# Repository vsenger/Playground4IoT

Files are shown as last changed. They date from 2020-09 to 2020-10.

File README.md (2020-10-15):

# Playground4IoT

*"There are three states of being: Not knowing, action and completion"*
Cult of Done Manifesto, Bre Pettis

Welcome Playgrounder to our repository where you can find libraries, firmwares, Arduino Sketch, tutorials and more for Playground4IoT development board. Playground4IoT is a development board that make easy and fun to start playing, prototyping and deploying connected devices projects using AWS Services like AWS IoT Core and Amazon FreeRTOS with security for adults, deployment over-the-air and management of big fleets of devices in production.

This project was done by AWS Developer Relations Team but is open-source, don't hesitate to clone it, produce, have fun, make money, change the world or anything else you dream. Developer Relations Team exist to help you to make it happen, count on us.. ALWAYS!

## Technical Resume

*"Accept that everything is a draft. It helps to get it done."*
The Cult of Done Manifesto, Bre Pettis

This board is based on ESP32, a powerful SoC that can run in low-energy with solar panel and simple battery forever and you can program using Arduino IDE, libraries and frameworks or you can go deeper and programa with Amazon FreeRTOS for industry ready devices.

* Based on ESP32 SoC (System-on-chip) with WIFI and Bluetooth
* Accelerometer Sensor
* Temperature, Humidity and Pressure sensor
* Light sensor
* Battery voltage sensor
* Solar panel sensor
* Groovy connectors
* External Solar Panel Connector
* External Battery Connector
* Battery charger system (cable / solar panel)
* And a lot of love!

## Let's Play!

*"People without dirty hands are wrong, doing something makes you right!"*
The Cult of Done Manifesto, Bre Pettis

Here we have a simple description image showing the main parts:

1. Power on / off
2. IoT Button: you can use as IoT button or anything else!
3. The loooovely OLED display: you can code turn on and off to save energy, sure thing!
4. ESP32: the core! and it's compatible with Amazon FreeRTOS and very cheap
5. GPIO: the place you can extend in a "maker way"
6. Reset Button
7. Solar panel connector: yesss! I can survive with Sun, at least in Brazil ahahah
8. External Battery Connector
9. USB C: you can use to charge the battery (nice!!!), to upload firmware hard-wire (but you can do it over-the-air!) or to debug your board
10. USB to Serial Controller: this is the CH340 chip, you may need or not to install a driver for it
11. You will find three additional connectors under the board and they are Grove compatible, so you can plug [200+ different sensors](https://www.seeedstudio.com/catalogsearch/result/index/?cat=890&q=grove).

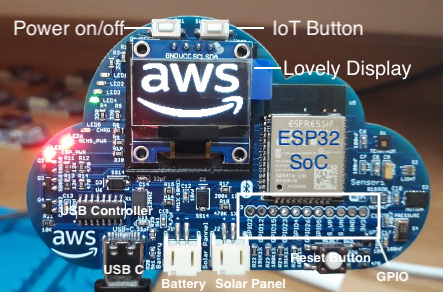
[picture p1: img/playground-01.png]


To start playing with this device (or toy?!?) we have those main steps:
1. Install Playground4IoT usb driver
1. Install and setup Arduino IDE environment: install Arduino IDE itself and setup for E	SP32 development 
1. Install Arduino libraries for the Playground4IoT sensors
1. Create a thing to represent your board in AWS IoT Core
1. Setup the wifi credential, root-ca, device certificate and private key inside the Arduino C code
1. Upload the Arduino code to your board using an USB cable
1. Open AWS IoT Core console and start playing with your board

Now let's go deep in each step!

## 1. Install Playground4IoT usb driver

Our board uses a chip called CH340 to communicate throught the USB-C port, this chip is actualy a Serial - USB converter so once you have the driver installed you will see the Playground4IoT as a Serial port (windows: COM1, COM7, COMx - linux /dev/acm0 /dev/usb0 - macs /dev/cu.wchusbserial). 

> **_NOTE:_**  MacOS Mojave (and newer) already includes a CH34x driver from Apple. Do not install other versions as it may cause issues. Read more on https://github.com/adrianmihalko/ch340g-ch34g-ch34x-mac-os-x-driver/pull/19.

Follow this nice sparkfun.com tutorial to install the driver: https://learn.sparkfun.com/tutorials/how-to-install-ch340-drivers/all

## 2. Arduino IDE

We have different ways to start programming our Playground4IoT that is based on ESP32 SoC and the simple way to do it is using Arduino IDE. It's a very popular IDE / tool for writing firmwares they call sketches using a simplified C sintax with many libraries to abstract all the hardware and C complex code.

To install Arduino IDE go to Arduino Web Site, download and install it, it's quite simlpe. Here is the link: https://www.arduino.cc/en/Main/Software

After installing the Arduino IDE we must add the ESP32 support. 

1) Open your Arduino IDE

2) Go to File -> Preferences

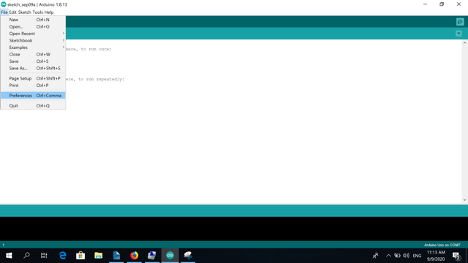
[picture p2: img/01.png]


3) Enter https://dl.espressif.com/dl/package_esp32_index.json into the “Additional Board Manager URLs” field as shown in the figure below. Then, click the “OK” button:

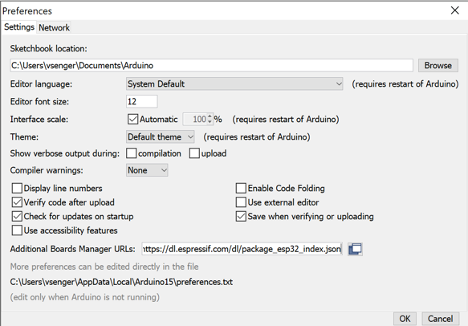
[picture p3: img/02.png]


4) Open the Boards Manager. Go to Tools > Board > Boards Manager…

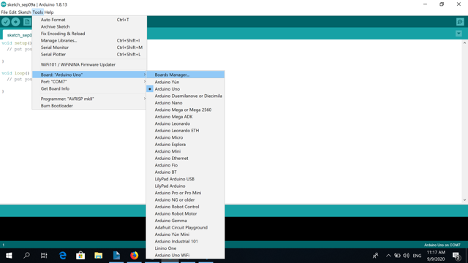
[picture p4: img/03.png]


5) Search for ESP32 and press install button for the “ESP32 by Espressif Systems“:

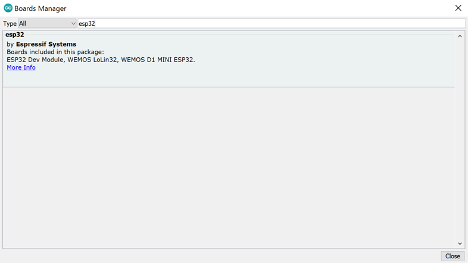
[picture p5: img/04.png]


Now wait until it finish the downlaod and install

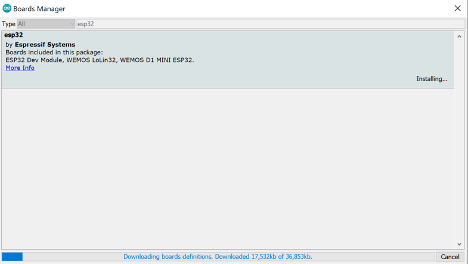
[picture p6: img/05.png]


All done with ESP32 support for Arduino IDE:

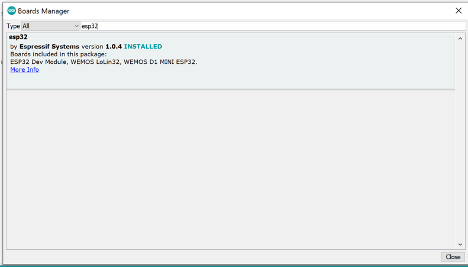
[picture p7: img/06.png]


6) Choose the "ESP32 Dev Module" in boards manager:

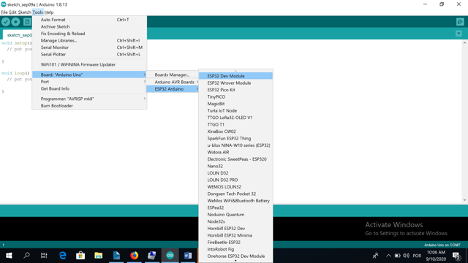
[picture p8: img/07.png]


7) Now it's time to find your USB port, don't plug your board in your computer and check which ports you have on the Tools -> Port menu:

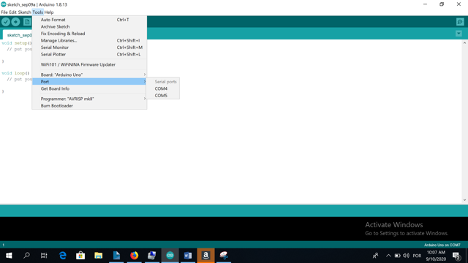
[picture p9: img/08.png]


8) Now plug your Playground4IoT and check this menu again, you should see something new like here that COM7 is the choosen port:

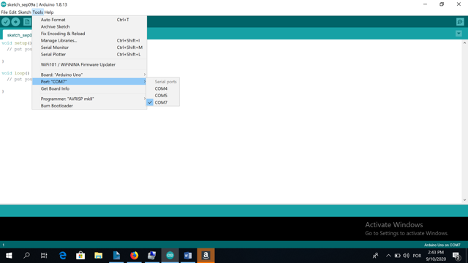
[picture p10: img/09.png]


## 3. Install Arduino Libraries for our Sensors

The Playground for IoT uses some sensors that has specific C libraries to make it easy to use. All we need to do is copy the folders in /Playground4IoT/Arduino/Libraries to your $HOME/Documents/Arduino/Library.

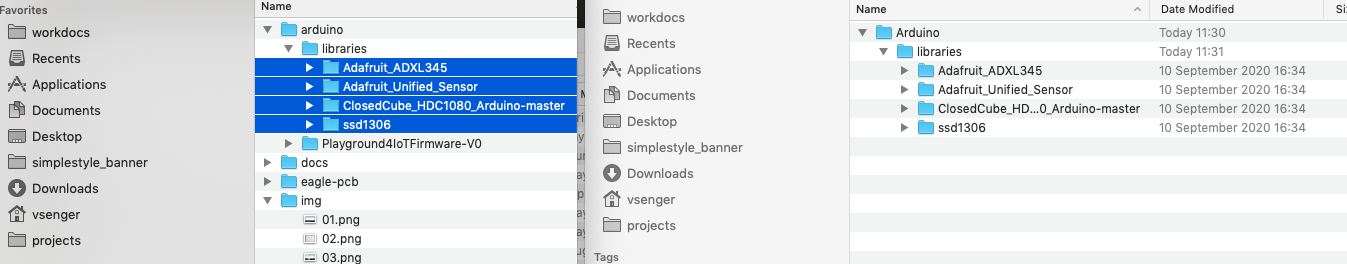
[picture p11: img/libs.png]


## 4. AWS IoT Core Setup

1) Now we need to setup the cloud side of the moon... We will create a thing to represent our Playground4IoT board and also the certificate and security keys. Open your AWS IoT Core Console and click Manage -> Things -> Register a single AWS IoT thing:

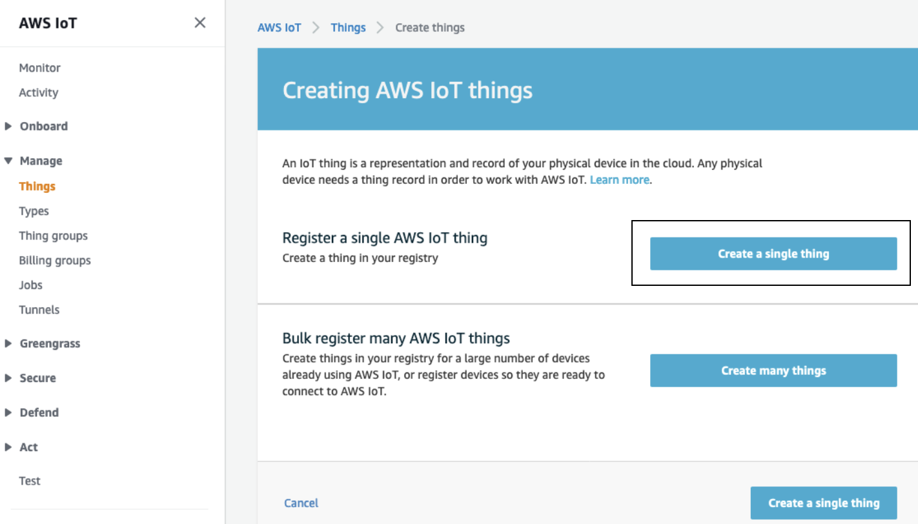
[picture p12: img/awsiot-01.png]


2) Let's choose "Create a single thing"

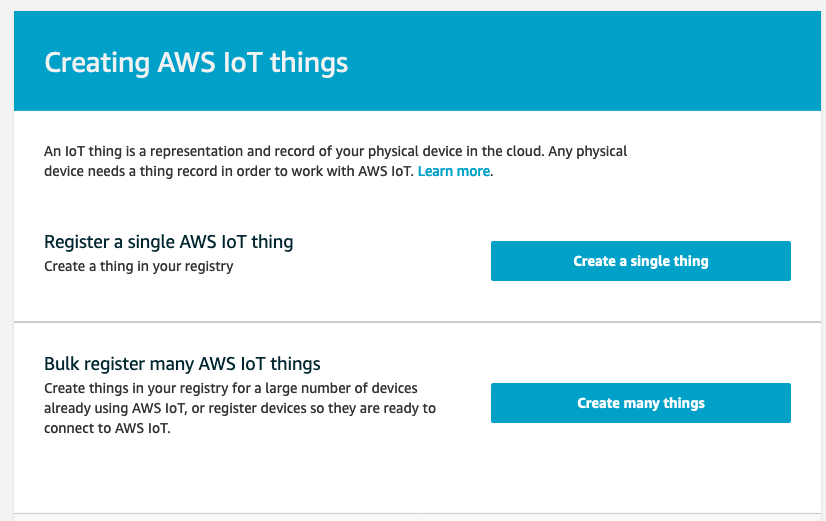
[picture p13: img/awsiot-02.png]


3) Now give a name to your thing and click next

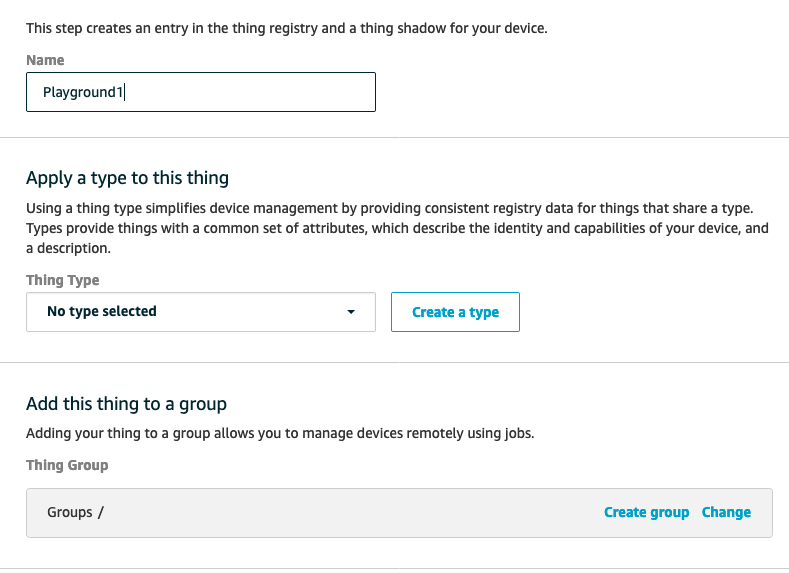
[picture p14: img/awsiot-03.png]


4) Now choose "One-click certificate creation"

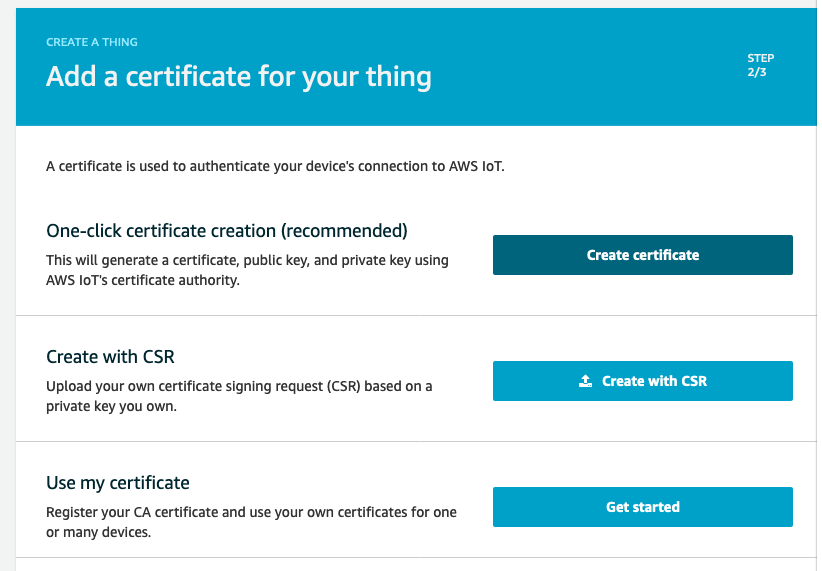
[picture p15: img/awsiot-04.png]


5) You can finally download your thing's certificate and private key

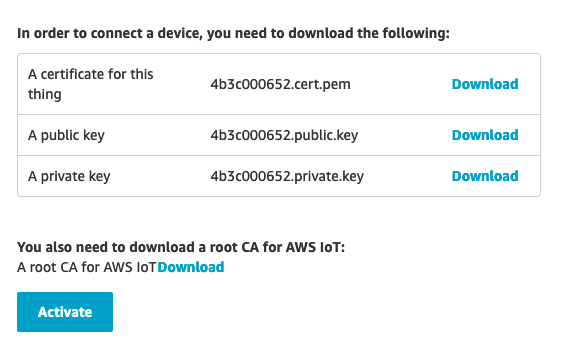
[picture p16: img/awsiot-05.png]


6) Click Activate to make your certicates valid

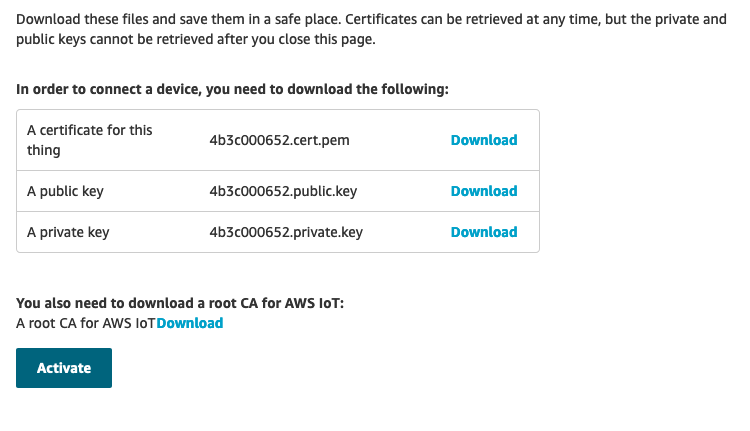
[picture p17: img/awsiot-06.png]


7) Download ROOT Certificate Authority clicking in "A root CA for AWS IoT Download" (this opens the AWS documentation and you'll need to choose one of the CAs on the page)

tutorial image

8) You will be redirected to another page that you can choose some options:

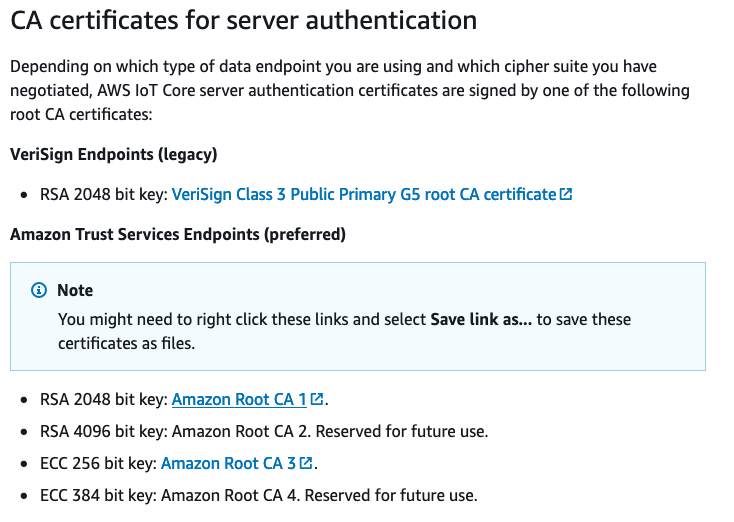
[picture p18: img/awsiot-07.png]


9) Now we need to take note of our AWS IoT Core endpoint to use in the next step. Open AWS IoT Core Console and click settings

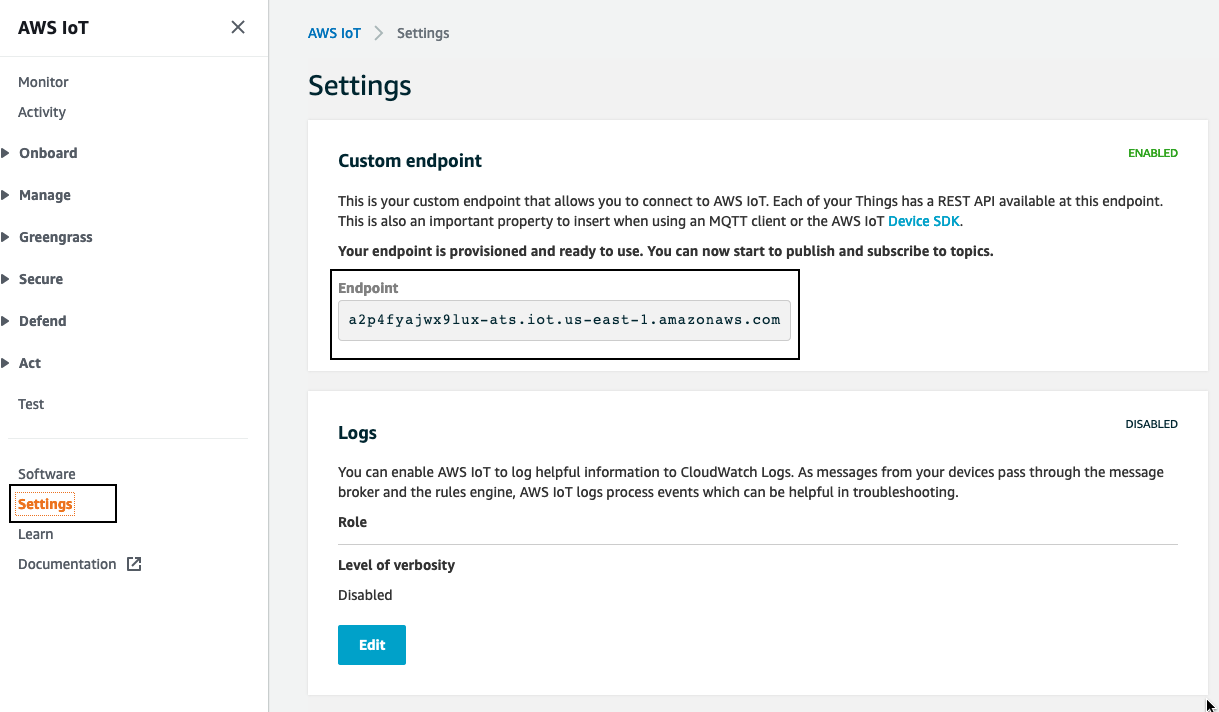
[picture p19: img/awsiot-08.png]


10) We need to create a policy for our device, click Policies -> Create

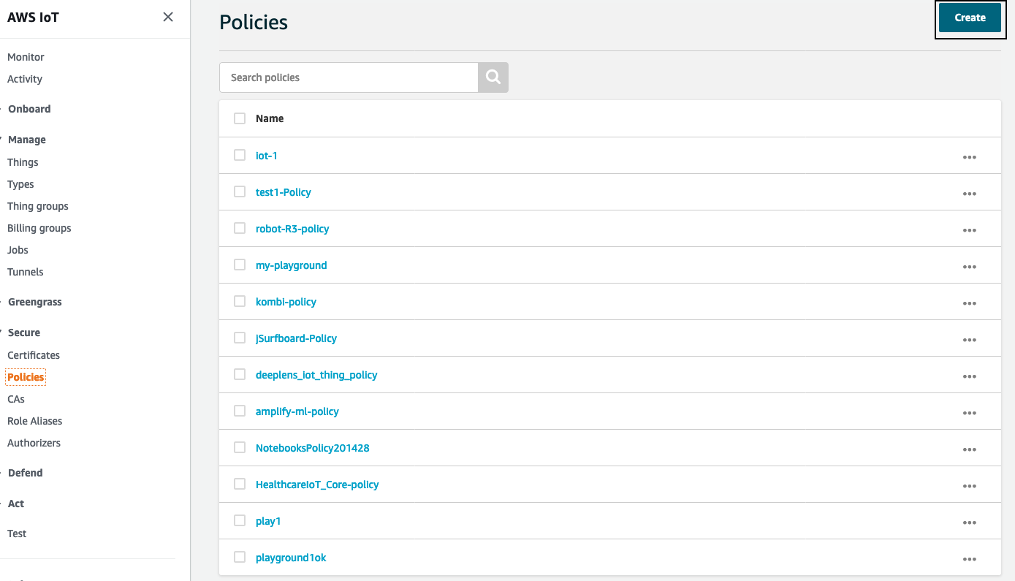
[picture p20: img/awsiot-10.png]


11) Give a name and choose action iot:* and replace topic name with * (just for testing proposal, the policy for real projects should be restrictive!). Choose Effect Allow and click Create

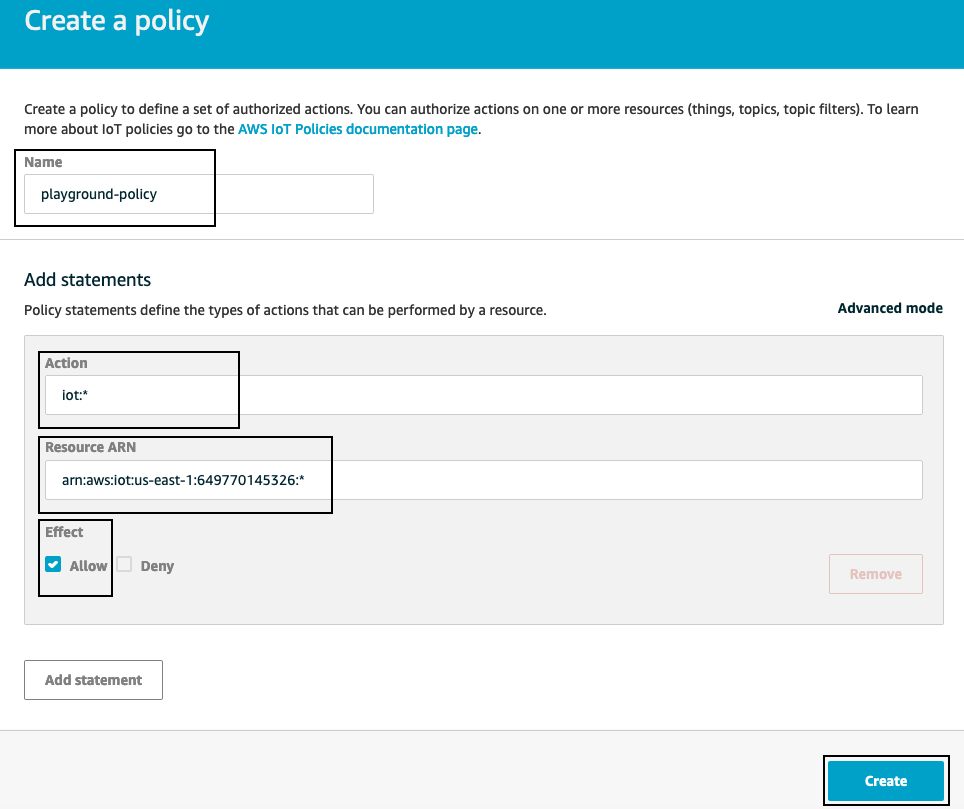
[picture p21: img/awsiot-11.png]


12) Now let's associate the policy with the Thing Certificate, to do this click in the IoT Thing you've created, click Security and then click in the Certificate:

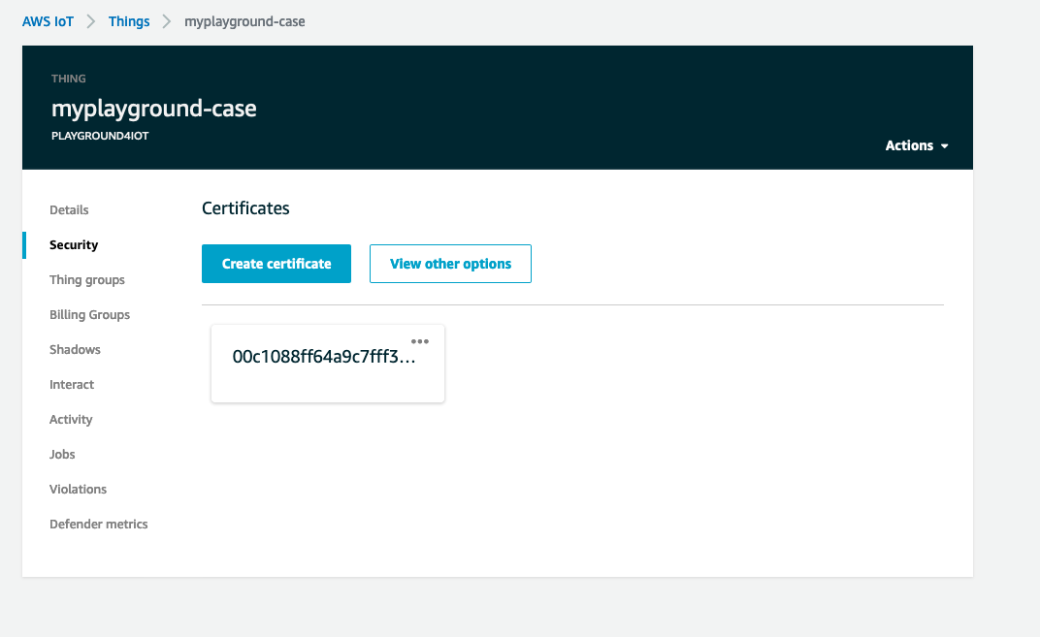
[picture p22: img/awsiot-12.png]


13) Click Policies

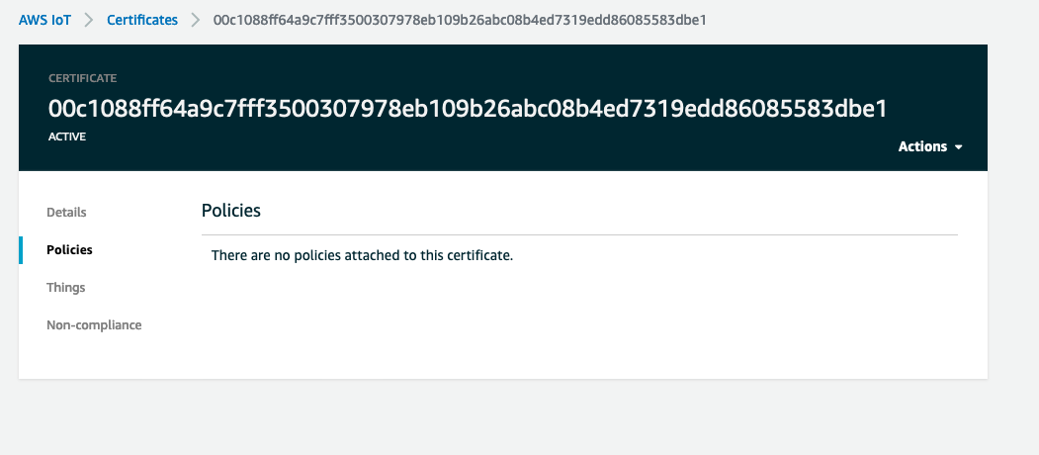
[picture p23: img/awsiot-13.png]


14) Click Actions menu -> Attach Policy

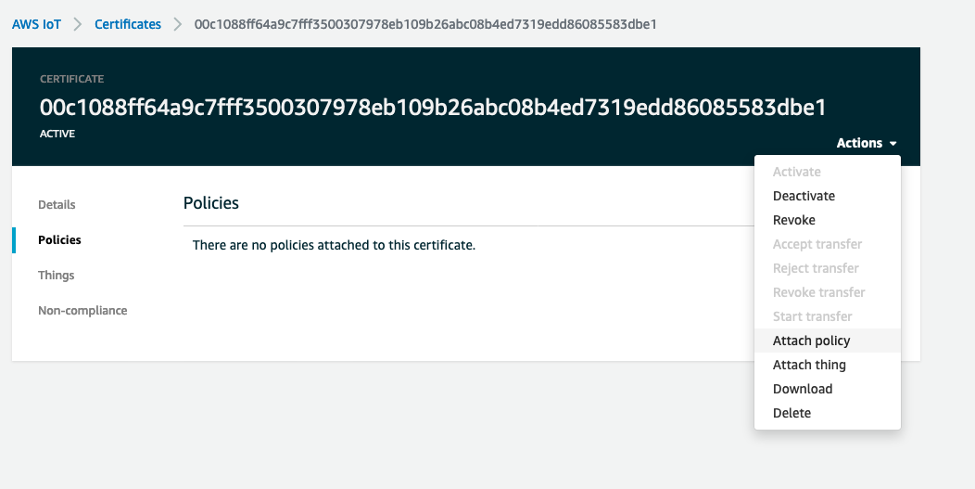
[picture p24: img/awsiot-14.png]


15) Choose the created Policy and click Attach:

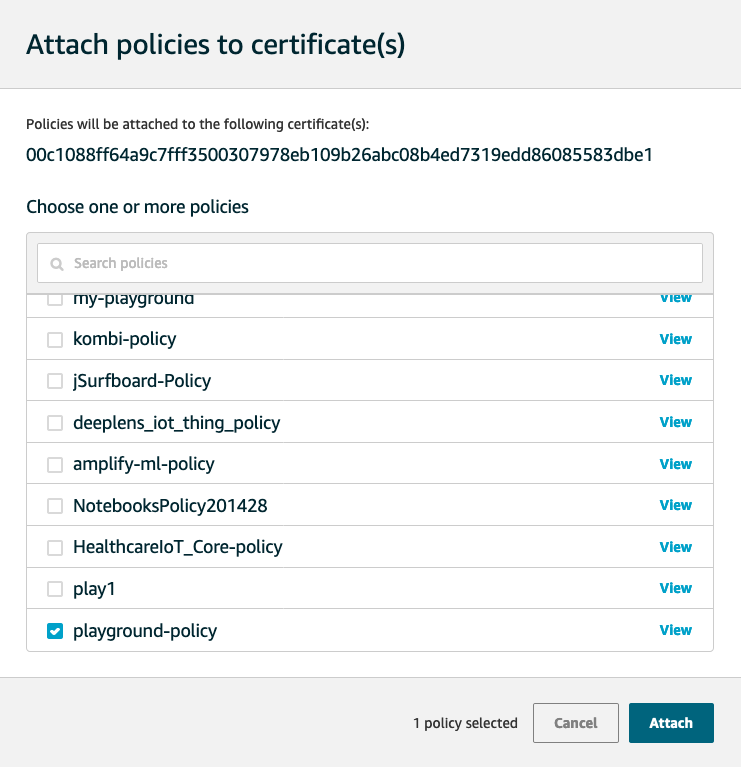
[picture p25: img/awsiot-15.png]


Ufff, done!

## 5. Let's code!

1) Clone Playground4IoT repo: git clone https://github.com/vsenger/Playground4IoT

2) Open your Arduino IDE and make sure you selected the right USB port and ESP32 board!

3) Open the Arduino Sketch with current the firmware located inside the folder you clone the github repo: Playground4IoT/arduino/Playground4IoTFirmware-V0/

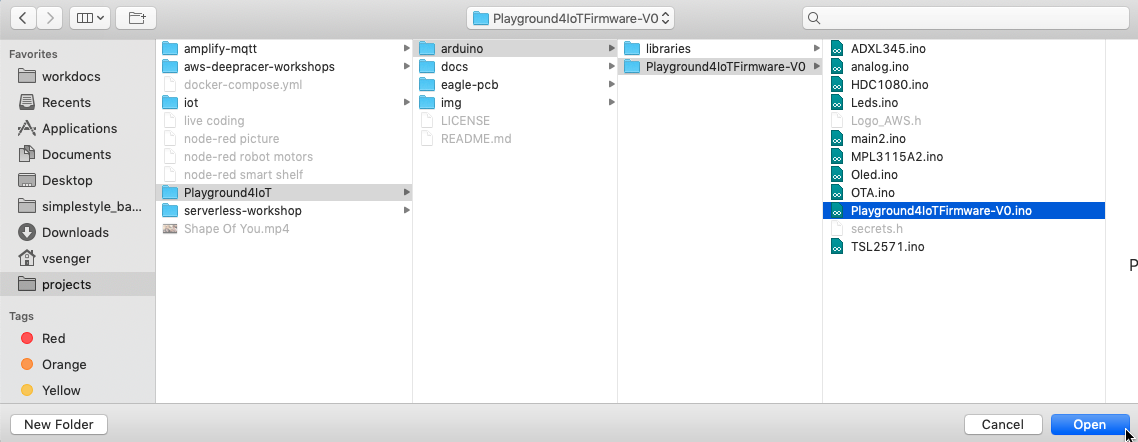
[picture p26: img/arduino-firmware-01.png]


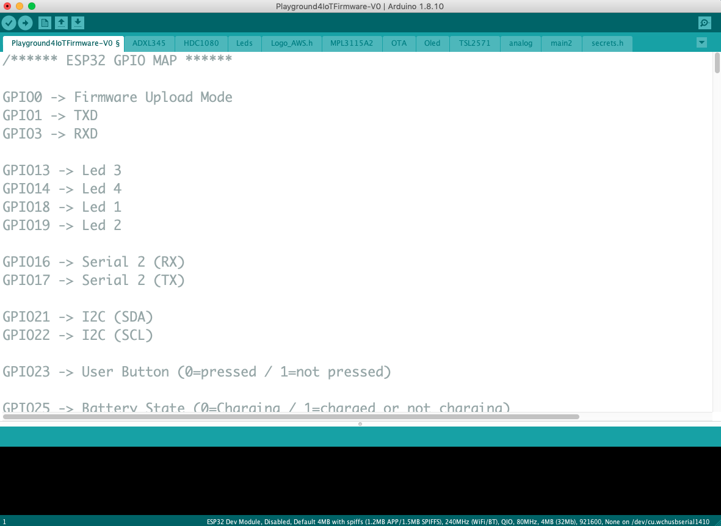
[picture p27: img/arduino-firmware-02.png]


4) Setup your SSID and password: scroll down to the line around 60 and change:

1. The host name to your AWS IoT Core Thing name
2. SSID and passsword
3. Optional: change the name of the topics we are going to use to communicate with our board 

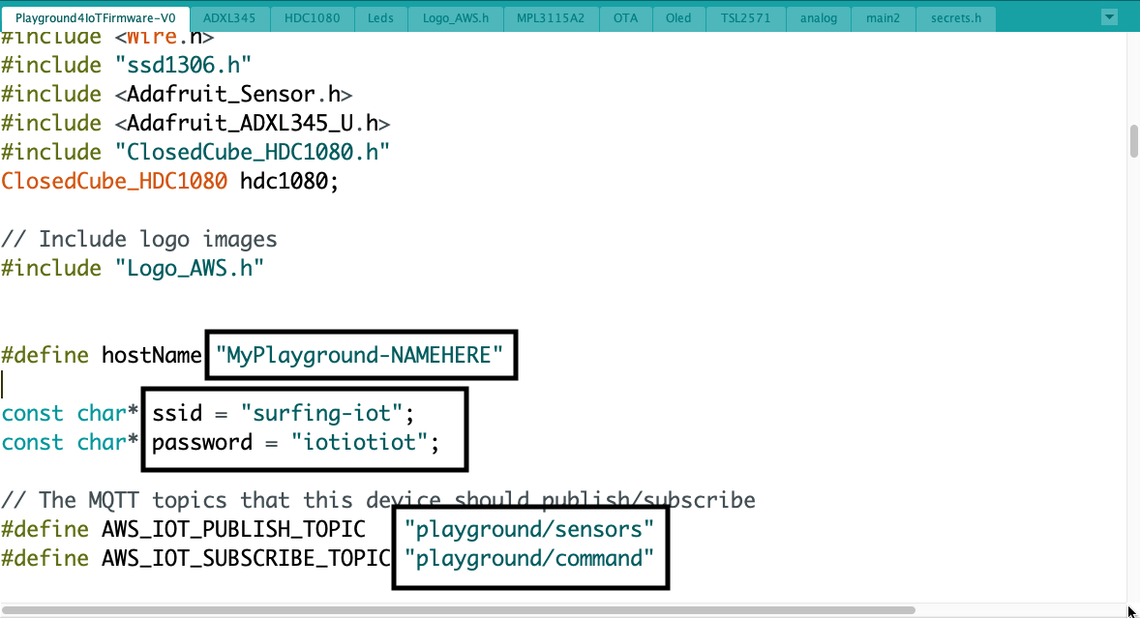
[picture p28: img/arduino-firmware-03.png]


5) Let's configure our credentials: click in secrets.h tab and then update:

1. AWS IoT Core endpoint
2. ROOT CA certificate: open the downloaded file and copy and paste the content
3. Same things for Device Certificate and Private Key. 

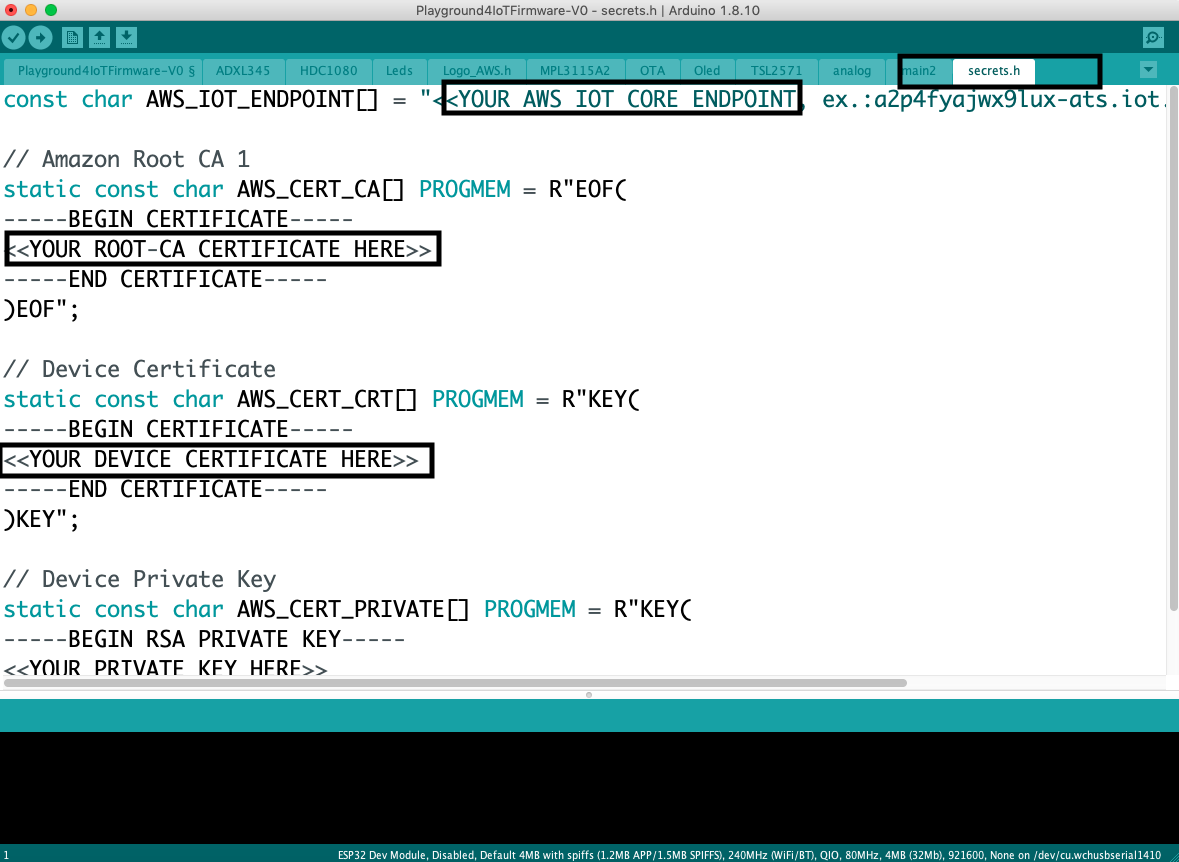
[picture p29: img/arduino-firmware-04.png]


## 6. Upload and fingers crossed

Now click the Upload button and wait until it compile and upload to your board. Keep your eyes in the log message panel, it's "normal" to have warning messages :).

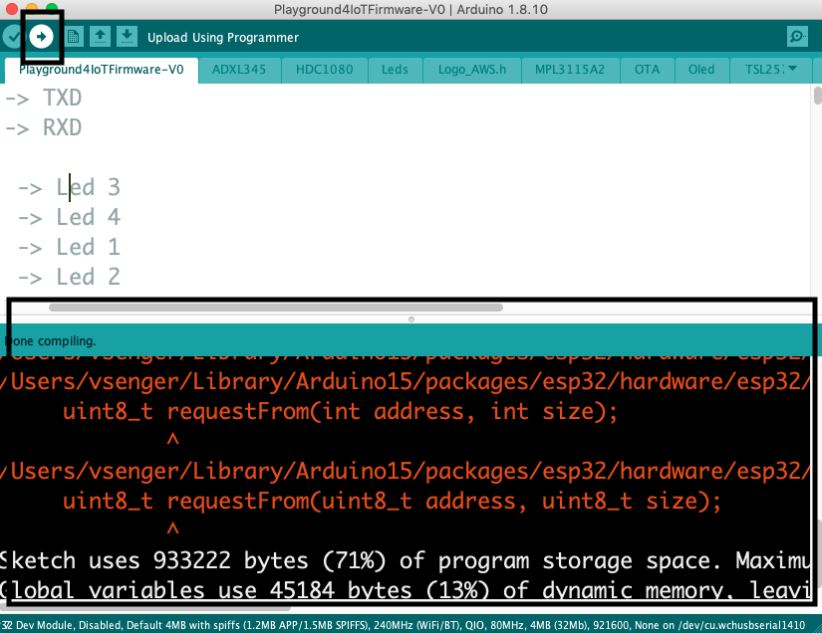
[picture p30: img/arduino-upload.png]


## 7. Let's Play! 

Time to have fun! Open your AWS IoT Core Console and click Test

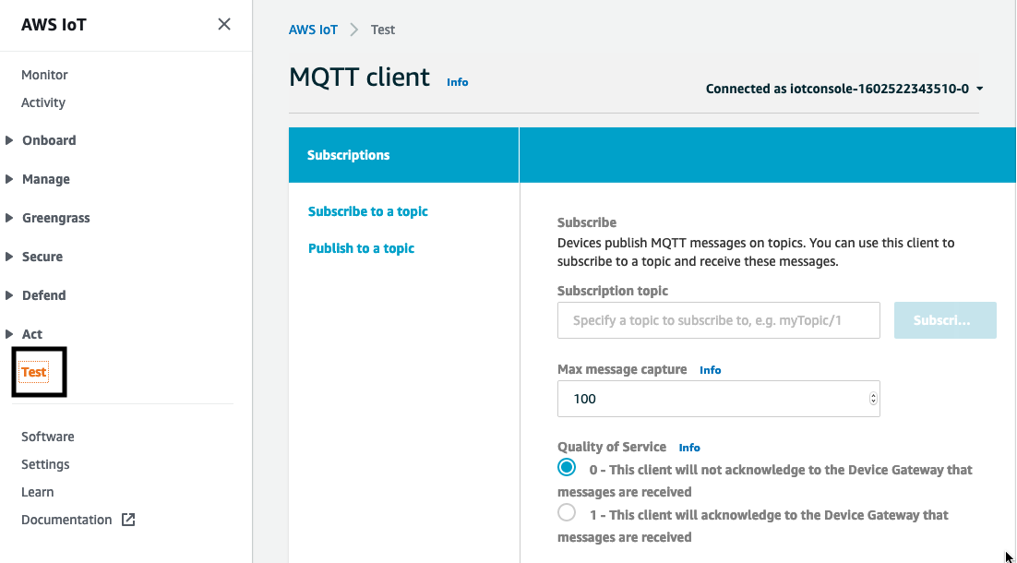
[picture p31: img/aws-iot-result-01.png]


Type playground/sensors and click Subscribe

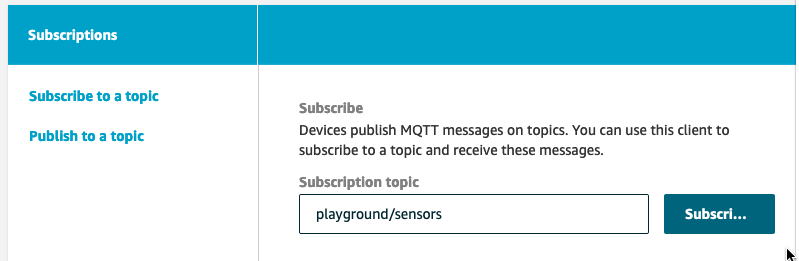
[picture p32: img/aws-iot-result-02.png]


Type playground/sensors and click Subscribe

Now you should start seeing the json results!

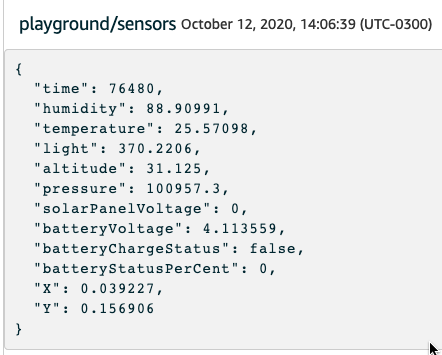
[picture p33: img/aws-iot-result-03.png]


## 8. Oppss, not working and now?

Chime Vini vsenger@ is now the first option but you can check the following:

1. Is your USB port ok?
2. Did you get any error message during the compile and upload process?
3. Did you choose the right Arduino Board setting to ESP32 Dev?
4. Can you open the Arduino Serial monitor?

## 9. More to come!

From here you can start changing the Arduino code to improve anything you want or do some local logic implementation reacting locally based on sensors data.

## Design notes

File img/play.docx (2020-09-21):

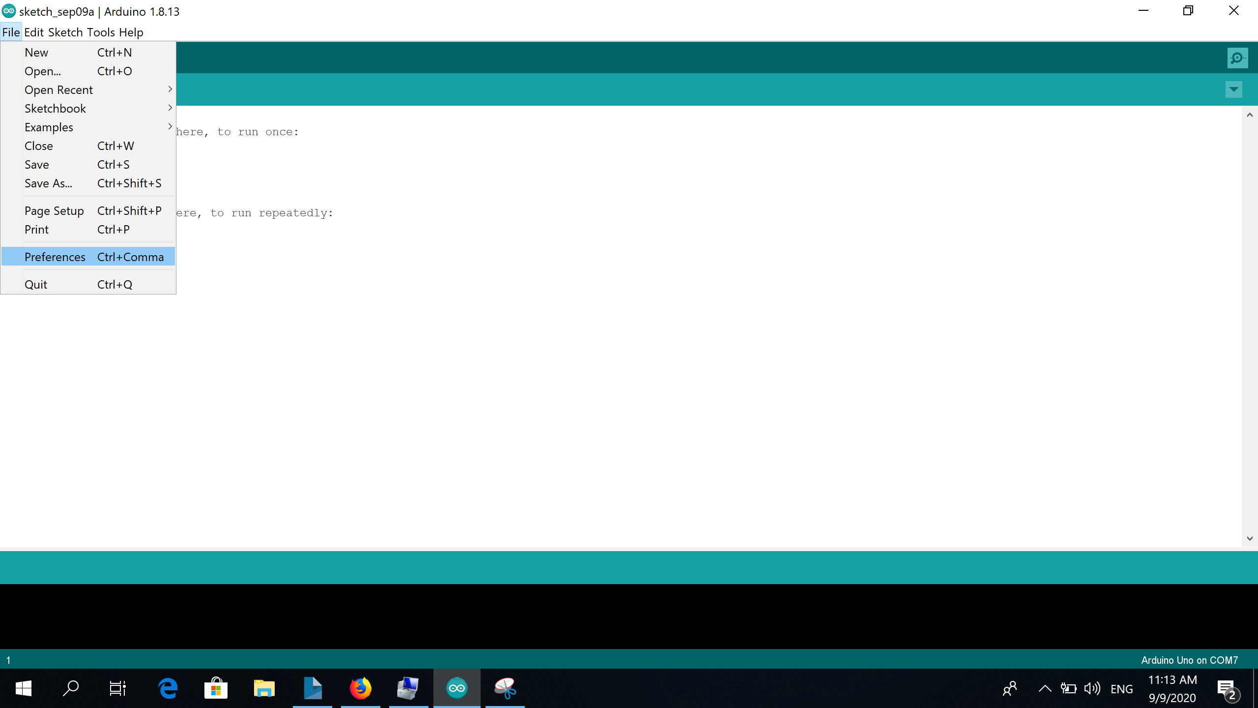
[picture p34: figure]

https://dl.espressif.com/dl/package_esp32_index.json

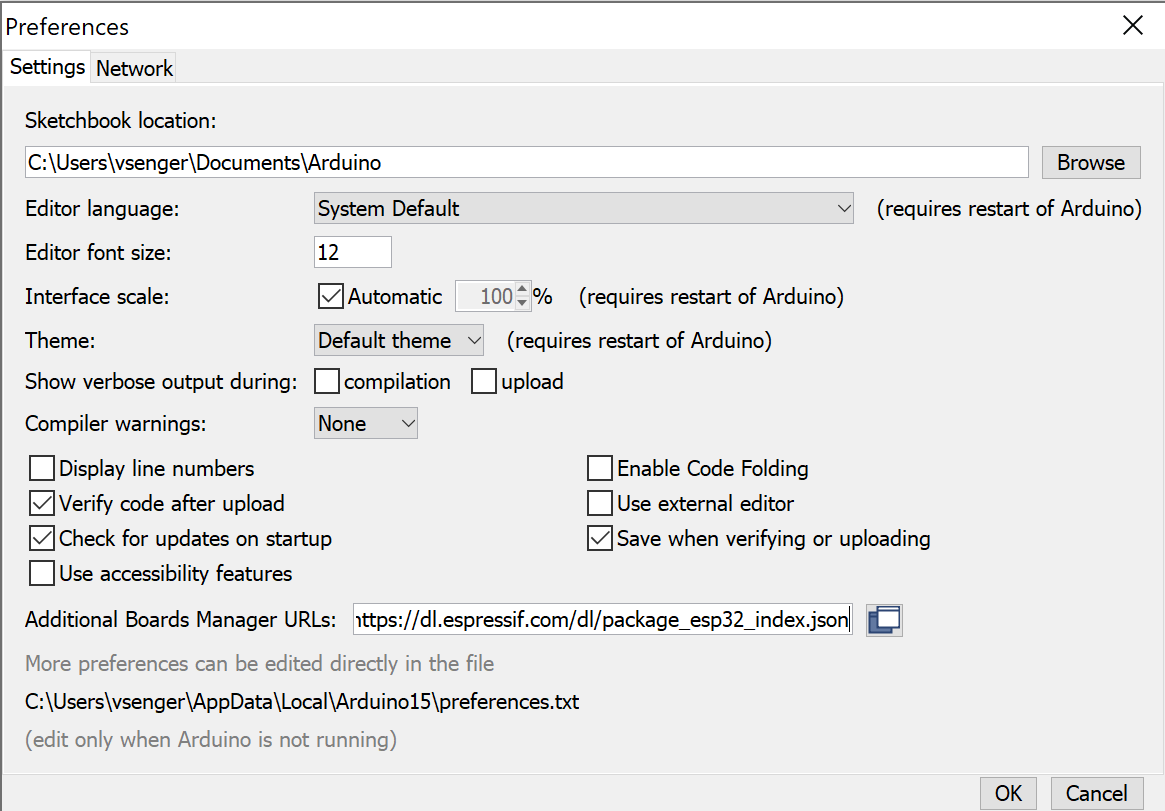
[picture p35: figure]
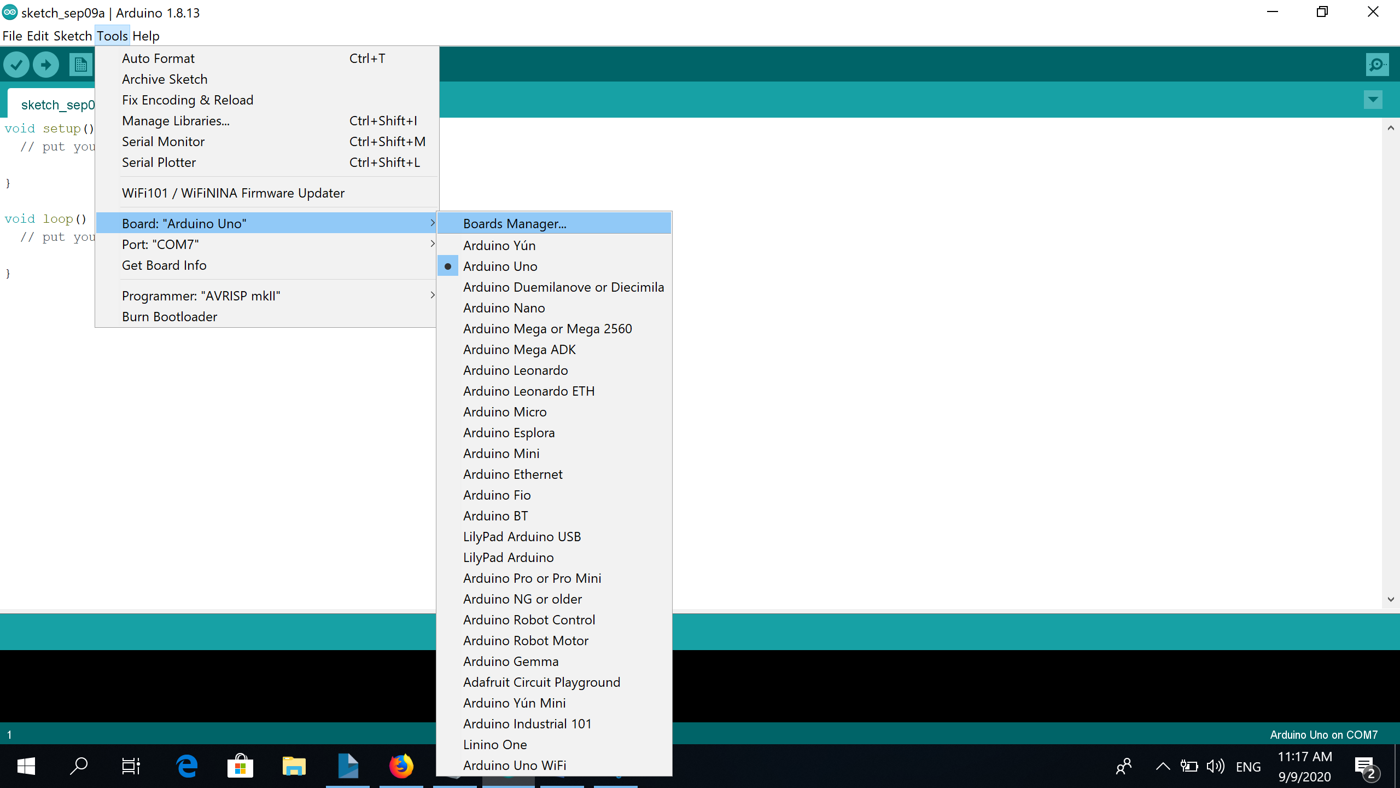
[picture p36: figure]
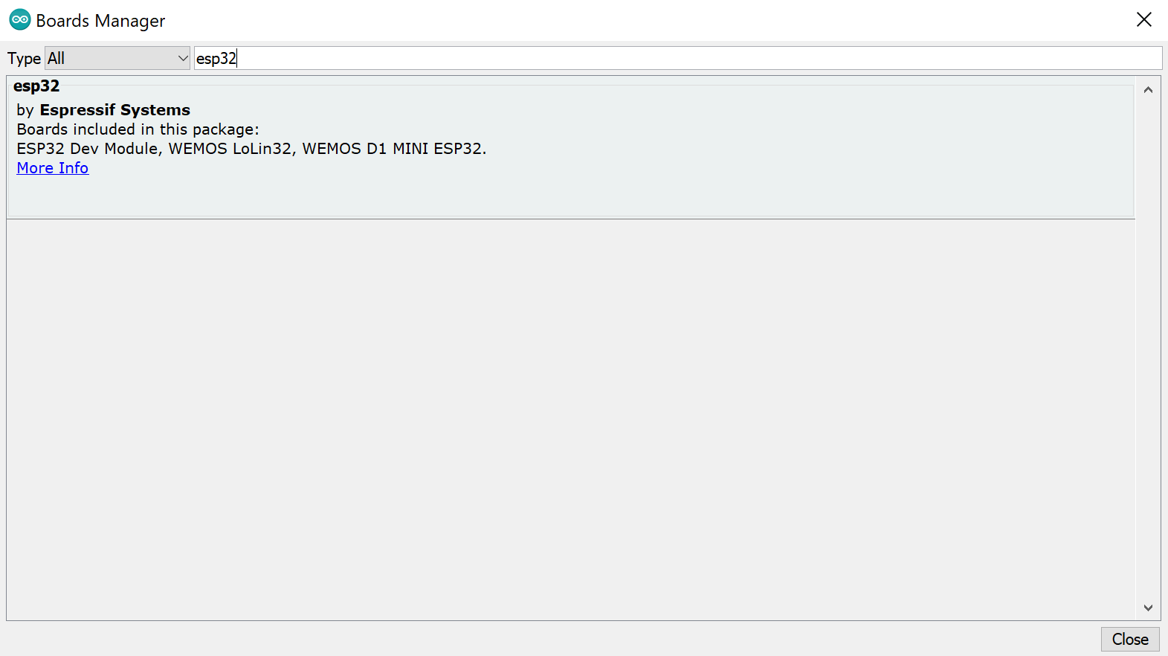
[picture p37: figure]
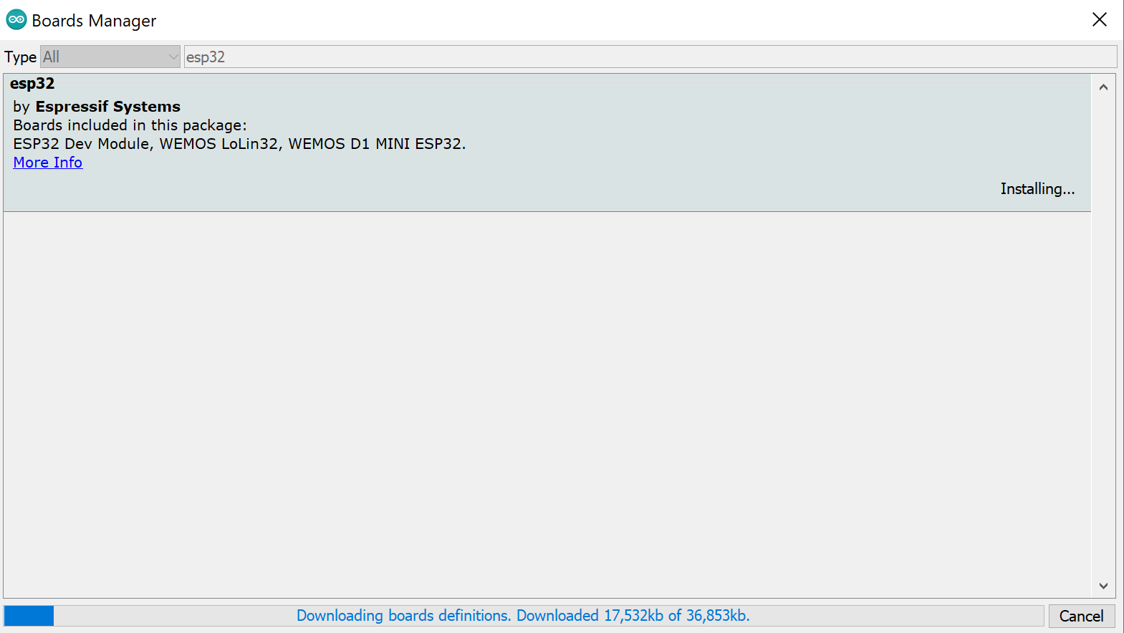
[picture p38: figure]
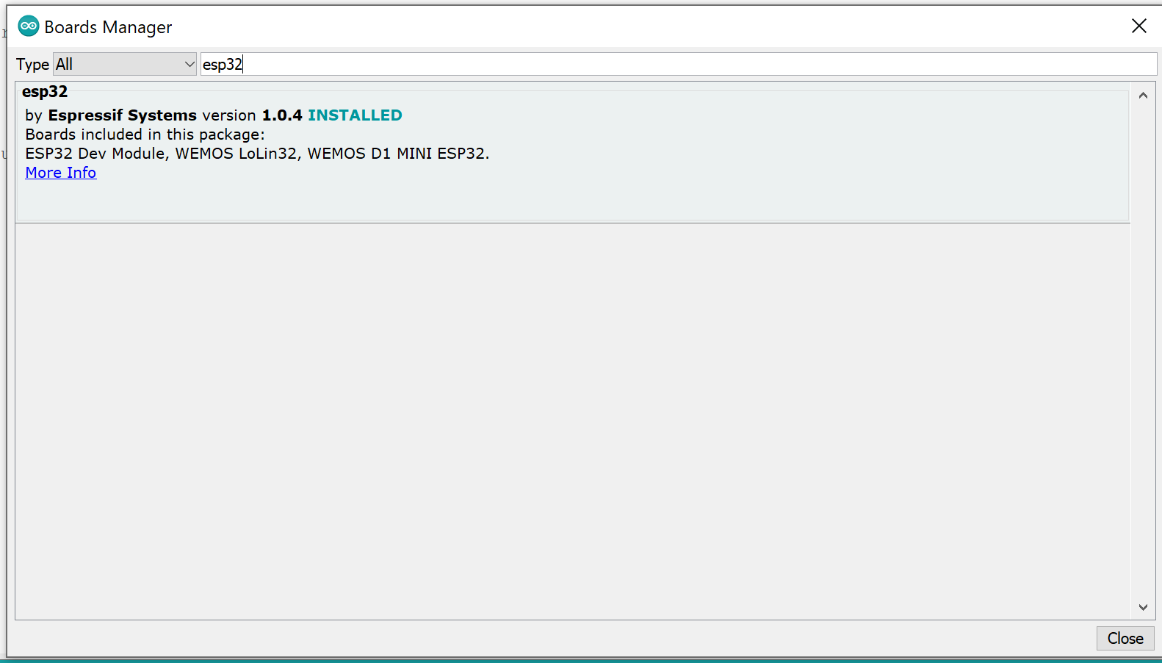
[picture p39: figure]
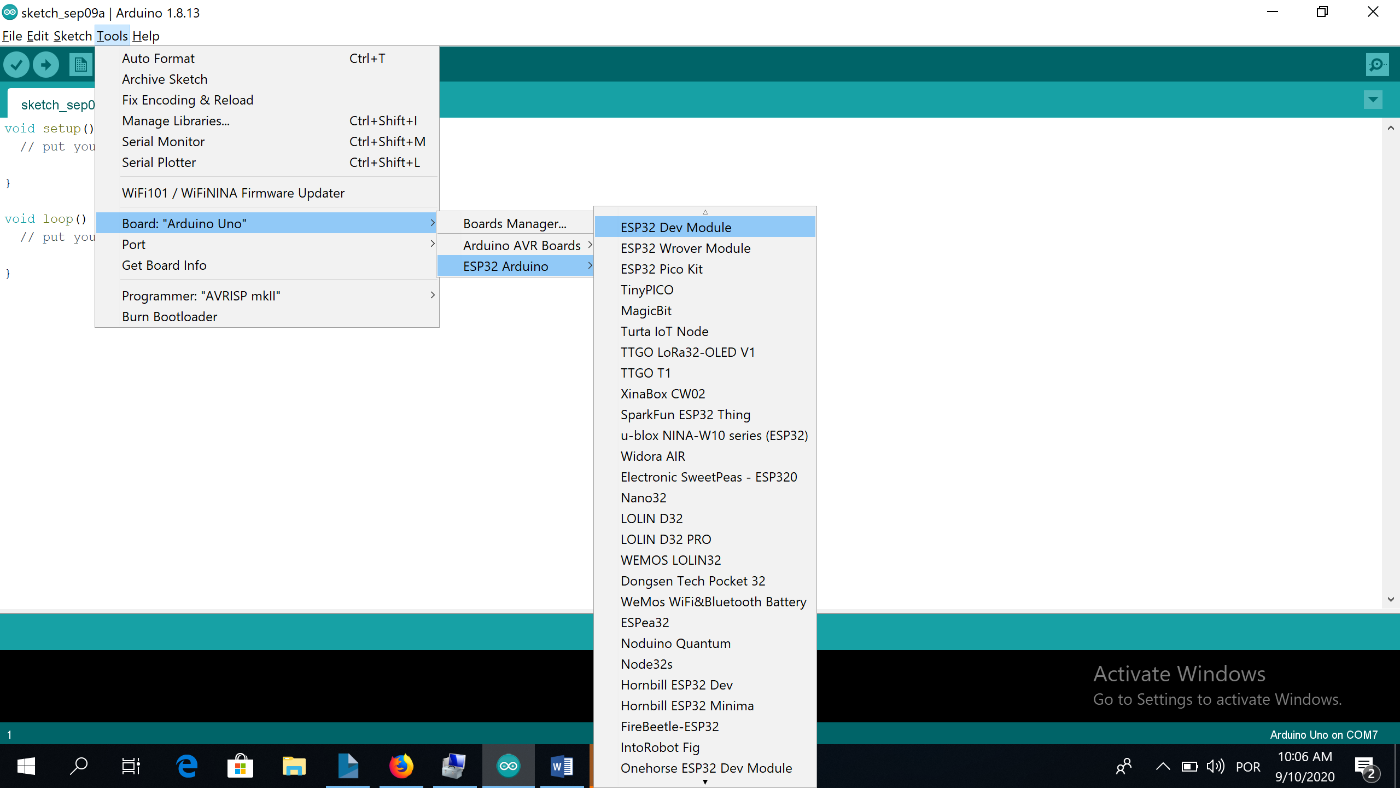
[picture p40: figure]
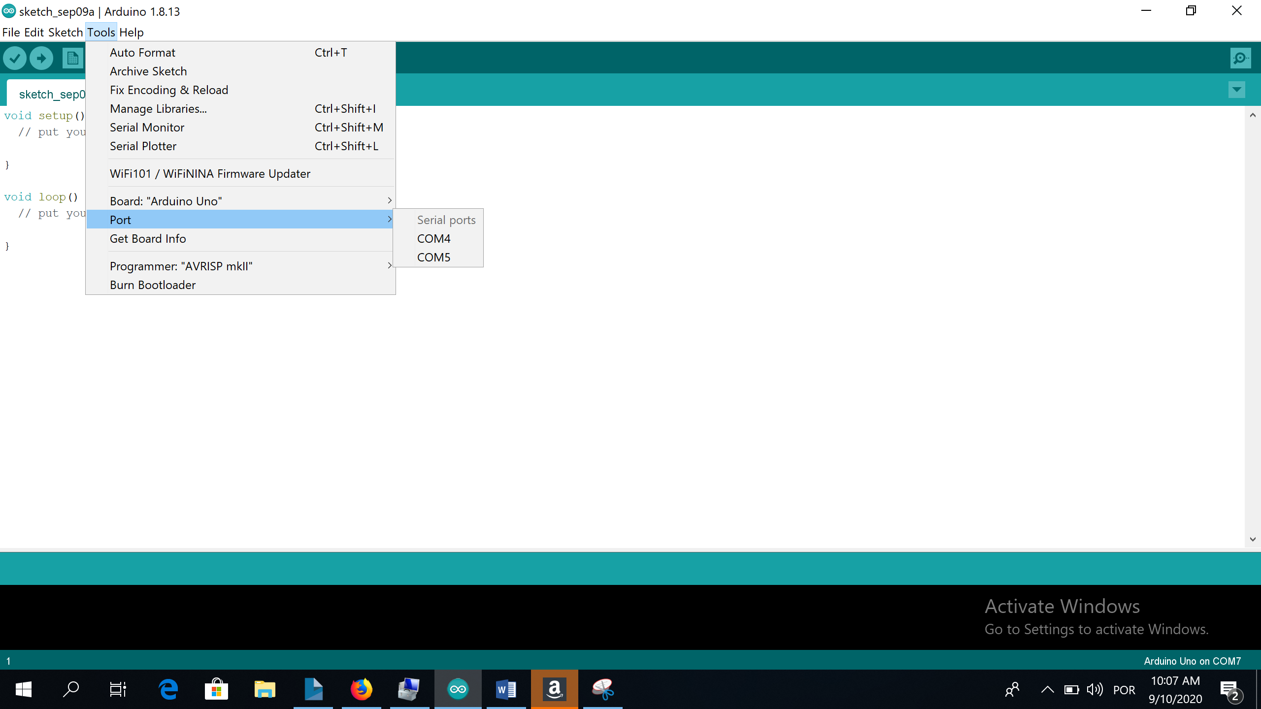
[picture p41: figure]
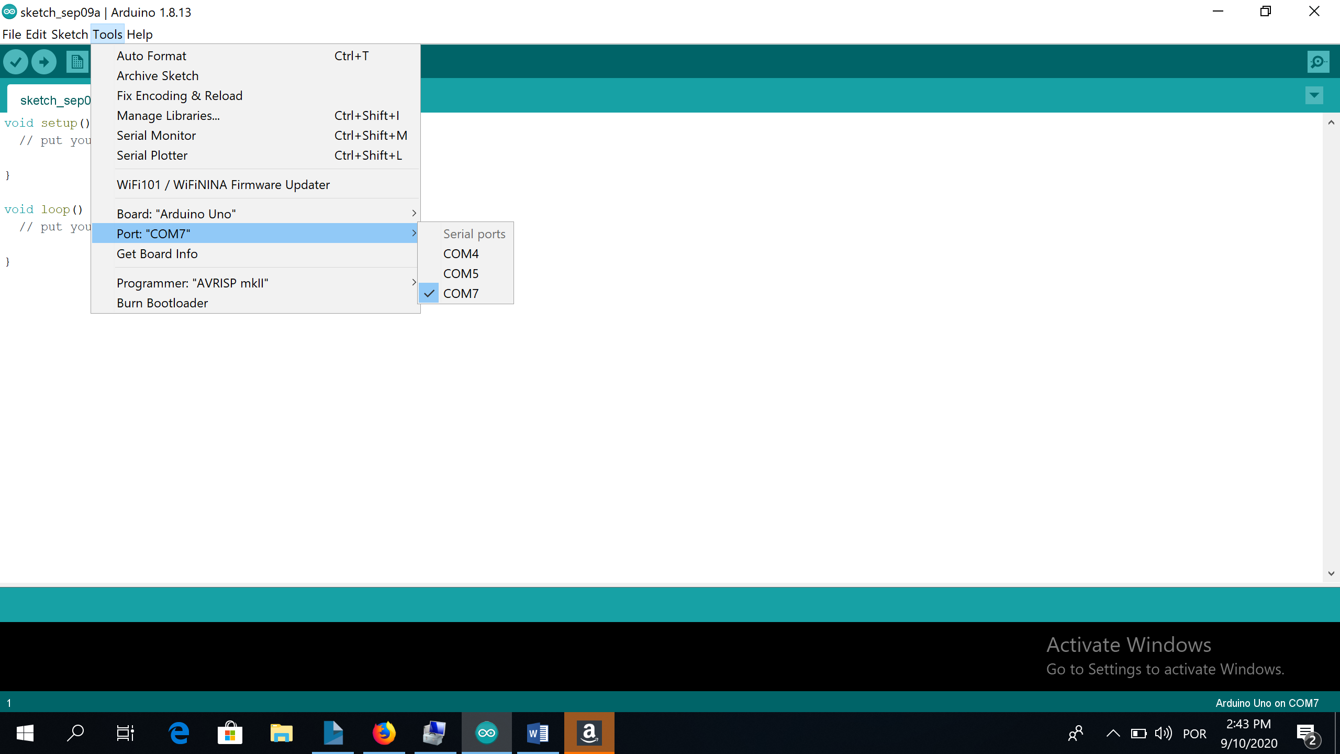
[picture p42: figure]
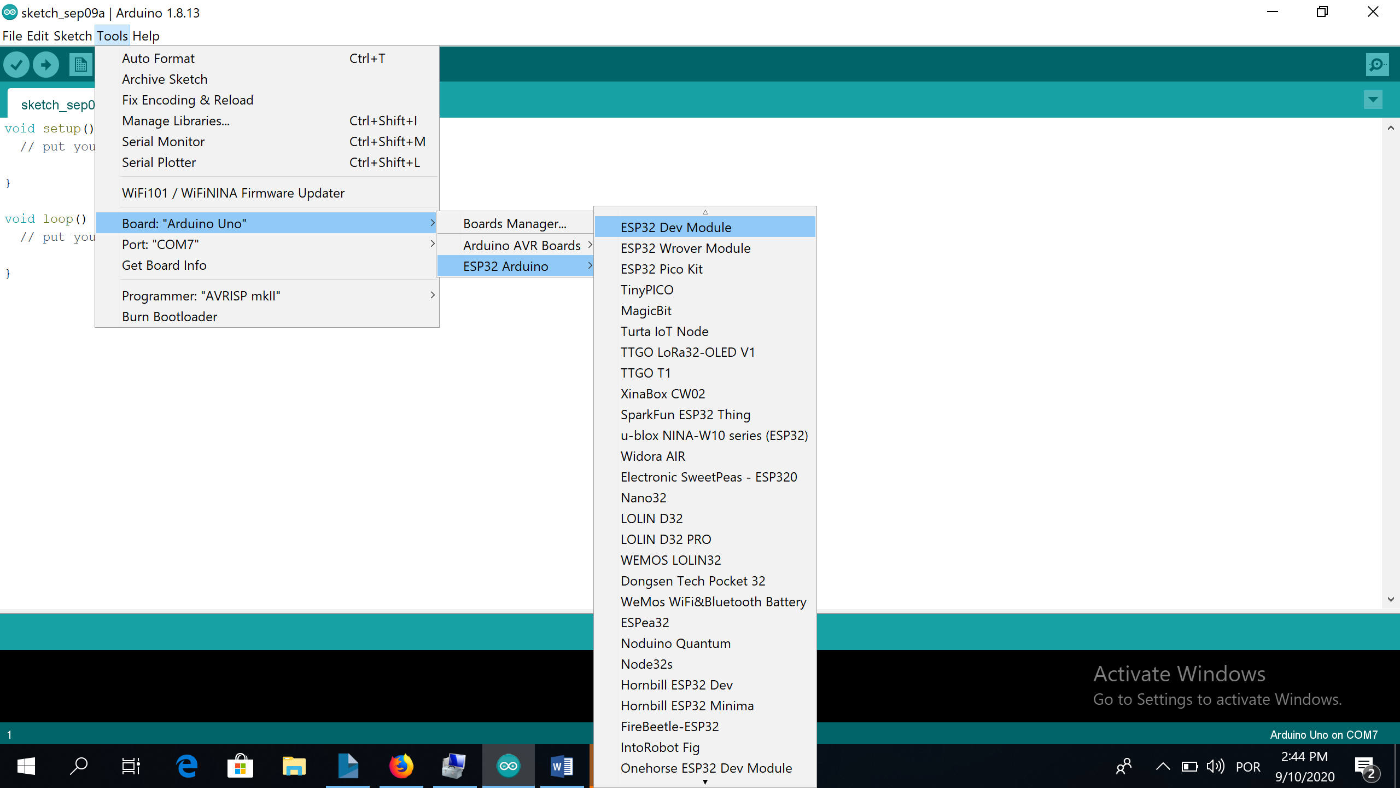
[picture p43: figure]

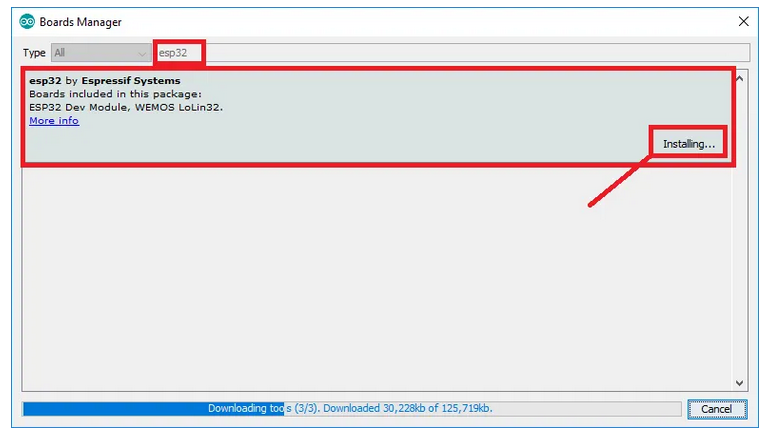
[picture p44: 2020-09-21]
img/05-ok.png

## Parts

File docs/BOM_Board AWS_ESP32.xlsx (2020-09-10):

TOTAL 20 Placas | Qty | Value | Device | Package | Description | MPN | Valor Unitario | Subtotal/PCB | Qtde Comprada
120 | 6 | 330 | RESISTOR 0805-RES | 0805 | 330 ±1% 1/8W ±100ppm/℃ 0805 Chip Resistor - Surface Mount RoHS | RC0805FR-07330RL | 0.009982 | 0.059892 | 150
20 | 1 | 2k | RESISTOR 0805-RES | 0805 | 2K ±1% 1/8W ±100ppm/℃ 0805 Chip Resistor - Surface Mount RoHS | RC0805JR-072KL | 0.023811 | 0.023811 | 40
80 | 4 | 10K | RESISTOR 0805-RES | 0805 | 10K ±5% 1/8W ±200ppm/℃ 0805 Chip Resistor - Surface Mount RoHS | CR0805J80103G | 0.002593 | 0.010372 | 50
20 | 1 | 1k | RESISTOR 0805-RES | 0805 | 1K ±0.1% 1/4W ±50ppm/℃ 0805 Chip Resistor - Surface Mount RoHS | RTT05102JTP | 0.057067 | 0.057067 | 100
40 | 2 | 12K | RESISTOR 0805-RES | 0805 | 12K ±5% 1/8W ±100ppm/℃ 0805 Chip Resistor - Surface Mount RoHS | AC0805FR-0712KL | 0.001853 | 0.003706 | 100
60 | 3 | 470 | RESISTOR 0805-RES | 0805 | 470 ±1% 1/8W ±100ppm/℃ 0805 Chip Resistor - Surface Mount RoHS | RC0805FR-07470RL | 0.002803 | 0.008409 | 100
20 | 1 | 10M 1% | RESISTOR 0805-RES | 0805 | 10M ±1% 1/8W ±100ppm/℃ 0805 Chip Resistor - Surface Mount RoHS | RMC080510M1%N | 0.004152 | 0.004152 | 50
20 | 1 | 4M 1% | RESISTOR 0805-RES | 0805 | 3.92M ±1% 1/8W ±100ppm/℃ 0805 Chip Resistor - Surface Mount RoHS | 0805W8F3924T5E | 0.001825 | 0.001825 | 100
20 | 1 | 280K 1% | RESISTOR 0805-RES | 0805 | 280K ±1% 1/8W ±100ppm/℃ 0805 Chip Resistor - Surface Mount RoHS | RC0805FR-07280KL | 0.003711 | 0.003711 | 50
20 | 1 | 470K 1% | RESISTOR 0805-RES | 0805 | 470K ±1% 1/8W ±100ppm/℃ 0805 Chip Resistor - Surface Mount RoHS | RTT054703FTP | 0.004955 | 0.004955 | 50
40 | 2 | 4K7 | RESISTOR 0805-RES | 0805 | 4.7K ±1% 1/8W ±100ppm/℃ 0805 Chip Resistor - Surface Mount RoHS | RS-05K4701FT | 0.007922 | 0.015844 | 100
40 | 2 | 191K1% | RESISTOR 0805-RES | 0805 | 191K ±1% 1/8W ±100ppm/℃ 0805 Chip Resistor - Surface Mount RoHS | AC0805FR-07191KL | 0.005412 | 0.010824 | 50
40 | 2 | 100K1% | RESISTOR 0805-RES | 0805 | 100K ±1% 1/8W ±100ppm/℃ 0805 Chip Resistor - Surface Mount RoHS | AF0805FR-07100KL | 0.007028 | 0.014056 | 50
60 | 3 | 2.2uf | CERAMIC-2.2UF-10V-10%-X7R(0603) | C0603 | 2.2uF ±10% 16V X5R 0603 Multilayer Ceramic Capacitors MLCC - SMD/SMT RoHS | 0603X225K160NT | 0.017376 | 0.052128 | 100
40 | 2 | 4.7uF | CERAMIC-4.7UF-10V-10%-X5R(0603) | C0603 | 4.7uF ±10% 16V X5R 0603 Multilayer Ceramic Capacitors MLCC - SMD/SMT RoHS | CL10A475KO8NNNC | 0.016509 | 0.033018 | 40
140 | 7 | 100nf | CERAMIC-100NF-50V-10%-X7R(0603) | C0603 | 100nF ±10% 50V X7R 0603 Multilayer Ceramic Capacitors MLCC - SMD/SMT RoHS | C0603B104K500NT | 0.007856 | 0.054992 | 150
20 | 1 | 1uF | CERAMIC-1UF-10V-10%-X5R(0805) | C0805 | 1uF ±10% 16V X7R 0805 Multilayer Ceramic Capacitors MLCC - SMD/SMT RoHS | 0805YC105KAT2A | 0.03795 | 0.03795 | 20
20 | 1 | 10uF x 16v | CAP-AVX-A | AVX-A. (1206) | 10uF ±10% 10V 3 Ω @ 100kHz -55℃ ~ +125℃ CASE-A_3216 Tantalum Capacitors RoHS | CA45-A-16V-10uF-K | 0.067255 | 0.067255 | 20
40 | 2 | 33pF | CERAMIC-10PF-50V-5%-NPO(0603) | C0603 | 33pF ±5% 50V C0G 0603 Multilayer Ceramic Capacitors MLCC - SMD/SMT RoHS | 0603N330F500CT | 0.01484 | 0.02968 | 50
20 | 1 | 10nf | CERAMIC-100NF-50V-10%-X7R(0603) | C0603 | 10nF ±5% 50V NP0 0603 Multilayer Ceramic Capacitors MLCC - SMD/SMT RoHS | CC0603JRNPO9BN103 | 0.071798 | 0.071798 | 50
20 | 1 | 12MHZ | SMD-CRYSTAL-12MHZ-20PF-20PPM-40R(2P-5.0X3.2MM) | X2-SMD-5.0X3.2X1.3MM | 12MHz ±30ppm 20pF 150Ω SMD-5032_2P SMD Crystal Resonators RoHS | XSHEELNANF-12MHZ | 0.160606 | 0.160606 | 20
60 | 3 | SS14 | DIODE-SCHOTTKY-SS14 | SMA-DIODE | SMA Schottky Barrier Diodes (SBD) RoHS | SS14 | 0.009605 | 0.028815 | 60
80 | 4 | SMD Green LED | LED0603 | LED-0603 | Green 520~535nm 0603 Light Emitting Diodes (LED) RoHS | 19-217/GHC-YR1S2/3T | 0.035455 | 0.14182 | 80
20 | 1 | SMD Yellow LED | LED0603 | LED-0603 | Yellow 585.5~594.5nm 0603 Light Emitting Diodes (LED) RoHS | 19-217/Y5C-AP1Q2/3T | 0.0020181 | 0.0020181 | 20
40 | 2 | SMD Red LED | LED0603 | LED-0603 | Red 617.5~633.5nm 0603 Light Emitting Diodes (LED) RoHS | 19-217/R6C-AL1M2VY/3T | 0.017727 | 0.035454 | 40
20 | 1 | CJ2307L | MOSFET_PCH-DMG2307L | SOT23-3 | P Channel 30V 2.7A 3V @ 250uA 138 mΩ @ 2.5A,4.5V 1.1W SOT-23(SOT-23-3) MOSFET RoHS | CJ2307 | 0.034356 | 0.034356 | 20
40 | 2 | S8050 | SMD-TRANSISTORS-NPN-25V-500MW-S8050(SOT-23) | SOT-23 | NPN 500mA 25V 300mW SOT-23 Transistors (NPN/PNP) RoHS | S8050 | 0.007591 | 0.015182 | 50
20 | 1 | CJ2302 | SMD-MOSFET-N-CH-20V-2.1A-CJ2302(SOT-23) | SOT-23 | N Channel 20V 2.1A 1.2V @ 50uA 60 mΩ @ 3.6A,4.5V 350mW SOT-23(SOT-23-3) MOSFET RoHS | CJ2302 S2 | 0.0308 | 0.0308 | 20
40 | 2 | AP2112 | V_REG_AP2112K-3.3V | SOT23-5 | Fixed 6V 3.3V 600mA SOT-25 Low Dropout Regulators(LDO) RoHS | AP2112K-3.3TRG1 | 0.124252 | 0.248504 | 40
20 | 1 | MAX16054 | MAX16054 | SOT23-6 | TSOT-23-6 Interface - Specialized RoHS | MAX16054AZT+T | 1.204545 | 1.204545 | 20
20 | 1 | MCP73831 | MCP73831 | SOT23-5 | MCP73831T Li-Ion, Li-Pol Controller. SOT-23-5 PMIC - Battery Management RoHS | MCP73831T-2ACI/OT | 0.393939 | 0.393939 | 20
20 | 1 | ESP-WROOM-03 | ESP-WROOM-03 | ESP-WROOM-03 | ESP32 Module WIFI Modules RoHS | ESP32-WROOM-32 | 2.615152 | 2.615152 | 20
20 | 1 | CH340G | CH340GSMD | SO016 | Transceiver USB 2.0 2Mbps SOP-16_150mil USB ICs RoHS | CH340G | 0.275758 | 0.275758 | 20
20 | 1 | TPS3839 | V_SUPERVISOR | SOT23-3 | Simple reset/Power-on reset 1 Push-pull,Totem pole Low effective 2.93V SOT-23(SOT-23-3) PMIC - Supervisors RoHS | TPS3839K33DBZR | 0.39697 | 0.39697 | 20
20 | 1 | HDC1080 | HDC1080 | WSON6 | Humidity, Temperature I²C 0 ~ 100% RH ±2% RH SMD Temperature & Humidity Sensors RoHS | HDC1080DMBR | 0.924242 | 0.924242
20 | 1 | TSL2571FN | TSL2571FN | FN-6 | TSL2571 illumination sensor |  | 1.959091 | 1.959091
20 | 1 | ADXL345 | ADXL345 | LGA-14 | Analog Devices ADXL345 3-Axis SPI/I2C 2/4/8/16g Accelerometer | ADXL345BCCZ-RL7 | 1.163636 | 1.163636 | 20
20 | 1 | MPL3115A2LGA8 | MPL3115A2LGA8 | LGA8 | Altimeter/Pressure Sensor, I2C, 1.95V-3.6V supply, 50 to 110kPa | MPL3115A2R1 | 1.951515 | 1.951515
40 | 2 | MOMENTARY-SWITCH-SPST-SMD-6.0X3.5MM | MOMENTARY-SWITCH-SPST-SMD-6.0X3.5MM | TACTILE_SWITCH_SMD_6.0X3.5MM | SPST 50mA @ 12VDC Top Actuated Rectangular Button SMD,6x3.5x4.3mm Tactile Switches RoHS | 1TS002C-2400-4300-CT | 0.02936 | 0.05872 | 40
20 | 1 | RESET | SMD-SWITCH-TACTILE-SPST-NO(4P-D6.0MM) | SW4-SMD-6.0X6.0X5.0MM | SPST 50mA @ 50VDC Top Actuated Round Button SMD Tactile Switches RoHS | TL3301NF260QG | 0.343939 | 0.343939 | 20
20 | 1 | USB-Conector Type-C16PIN | SMD USB Connectors RoHS | TYPE-C16PIN | SMD USB Connectors RoHS | TYPE-C16PIN | 0.112005 | 0.112005 | 20
40 | 2 | 2P-2.0-90D-SMD | CONN-HEADER-SMD-PH-SIDE-(2P-2.0MM) | HW2-SMD-2.0-90D | JST P=2mm Wire To Board / Wire To Wire Connector RoHS | S2B-PH-SM4-TB(LF)(SN) | 0.137879 | 0.275758
20 | 1 | Generic Header-pin footprint for 0.1 inch spaced | CONN_11 | 1X11 | Pin Header Male Pin 0.100"(2.54mm) 11 1 Through Hole,P=2.54mm Pin Header & Female Header RoHS | A2541WV-11P | 0.121264 | 0.121264 | 20
60 | 3 | 4P-SMD-2.0-90D | GROVE-CONNECTOR-SMD-90D(4+2P-2.0) | HW4-SMD-2.0-90D | PA Header Male Pin 0.079"(2.00mm) 4 Through Hole,P=2mm Wire To Board / Wire To Wire Connector RoHS | SM04B-PASS-TBT(LF)(SN) | 0.368182 | 1.104546 | 60
20 | 1 | PCB Customizada | PCB (56,6 x 90.0) |  | Customized PCB 2 layers |  | 1.29 | 1.29
 |  |  |  |  |  |  | TOTAL/PCB US$ | 15.4540801
20 | 1 | DISPLAY-OLED-128X64 | DISPLAY-OLED-128X64-I2C | DISPLAY-OLED-128X64-I2C | 128x64 Dot Matrix OLED Module based on SSD1306 chip | MERCADOLIVRE | R$23 | 5
 |  |  |  |  |  |  | TOTAL com Display US$ | 20.4540801

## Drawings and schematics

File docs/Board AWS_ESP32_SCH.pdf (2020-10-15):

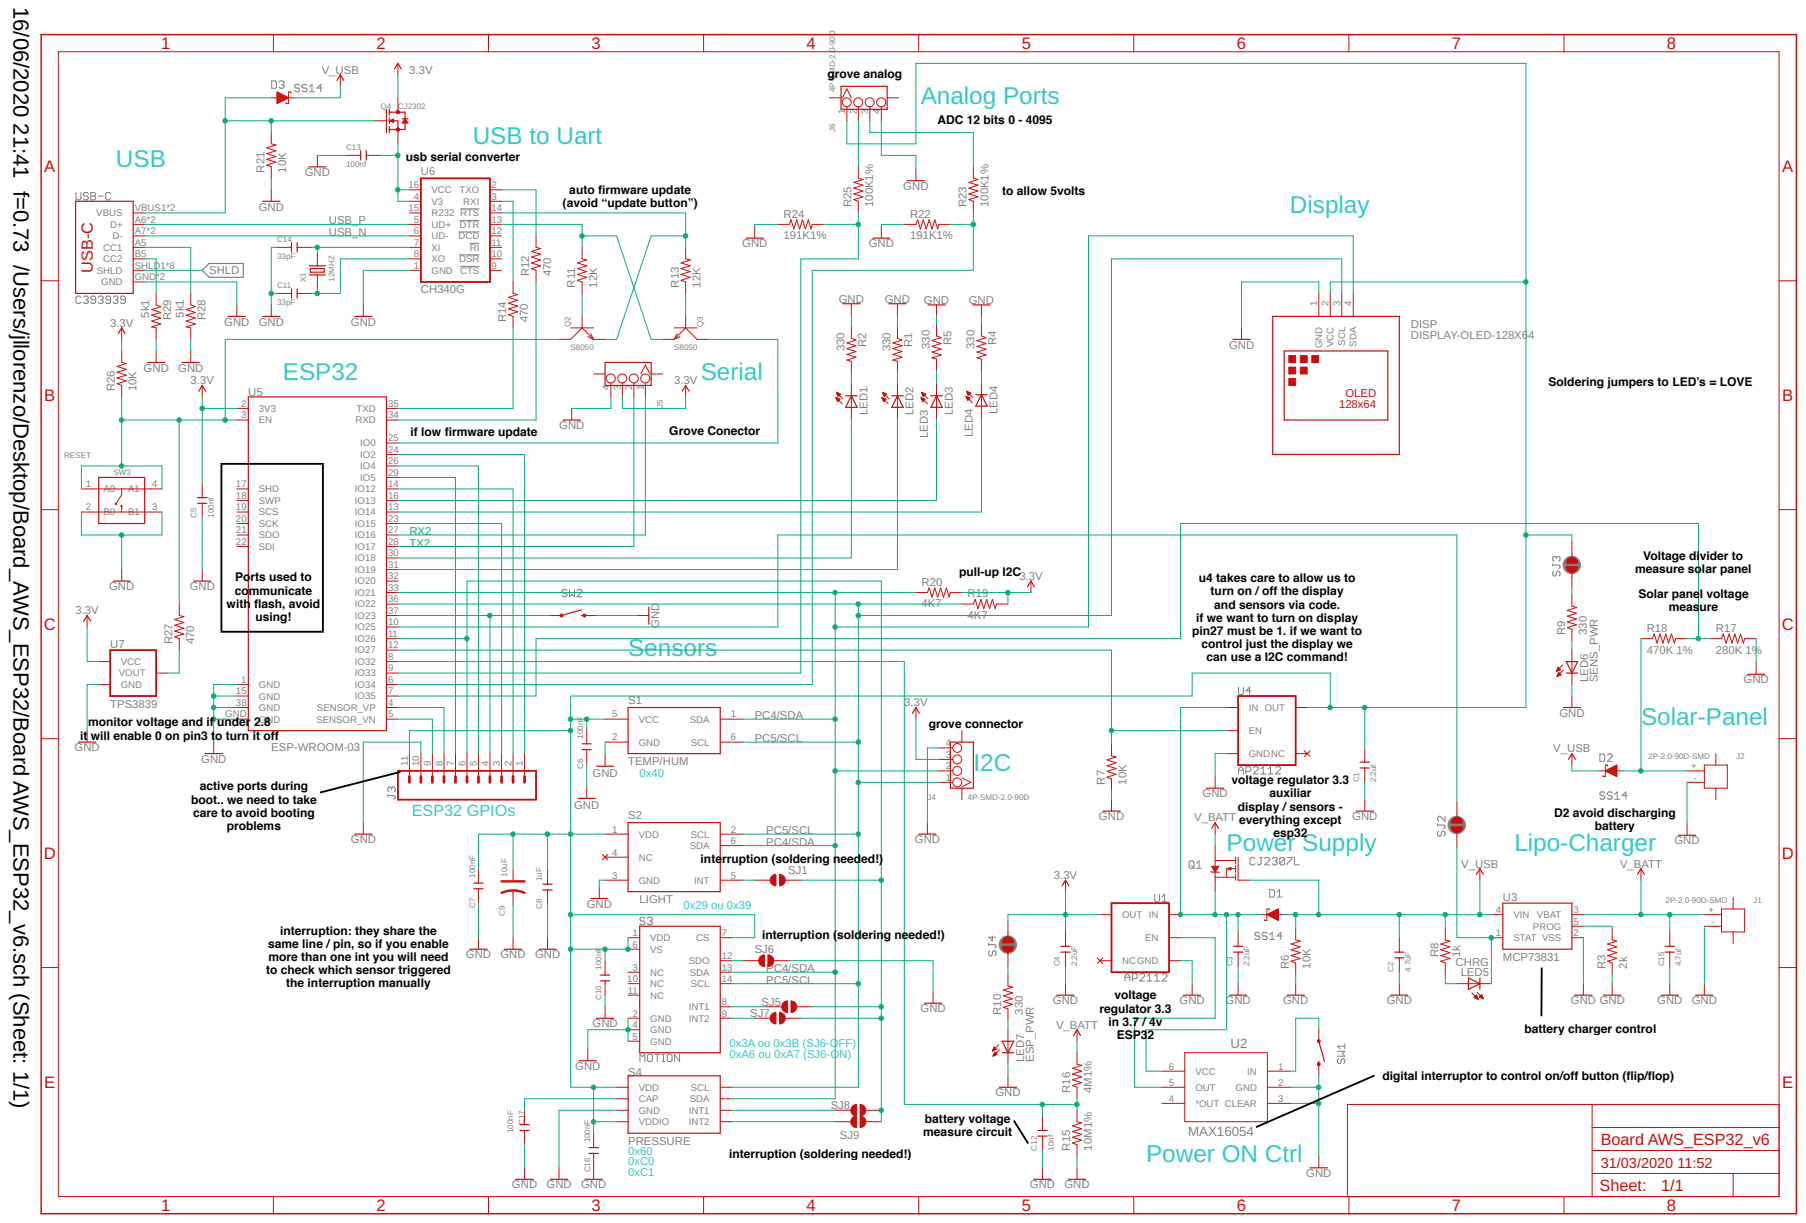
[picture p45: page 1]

16/06/2020 21:41 f=0.73 /Users/jllorenzo/Desktop/Board_AWS_ESP32/Board AWS_ESP32_v6.sch (Sheet: 1/1)

30
31
32

37
10
11

IN GND OUT EN

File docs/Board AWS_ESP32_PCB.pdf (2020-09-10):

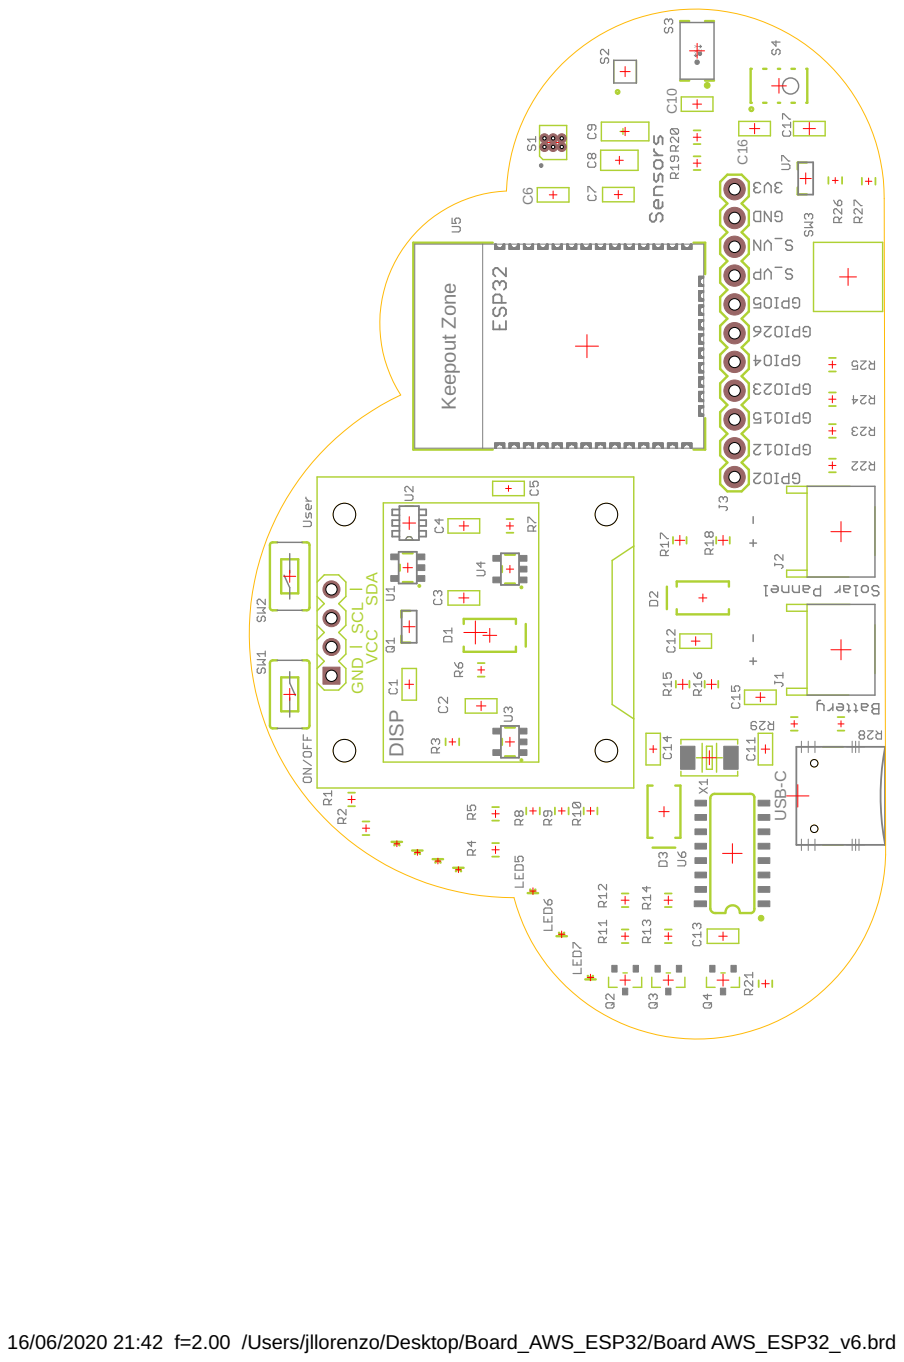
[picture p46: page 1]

16/06/2020 21:42 f=2.00 /Users/jllorenzo/Desktop/Board_AWS_ESP32/Board AWS_ESP32_v6.brd

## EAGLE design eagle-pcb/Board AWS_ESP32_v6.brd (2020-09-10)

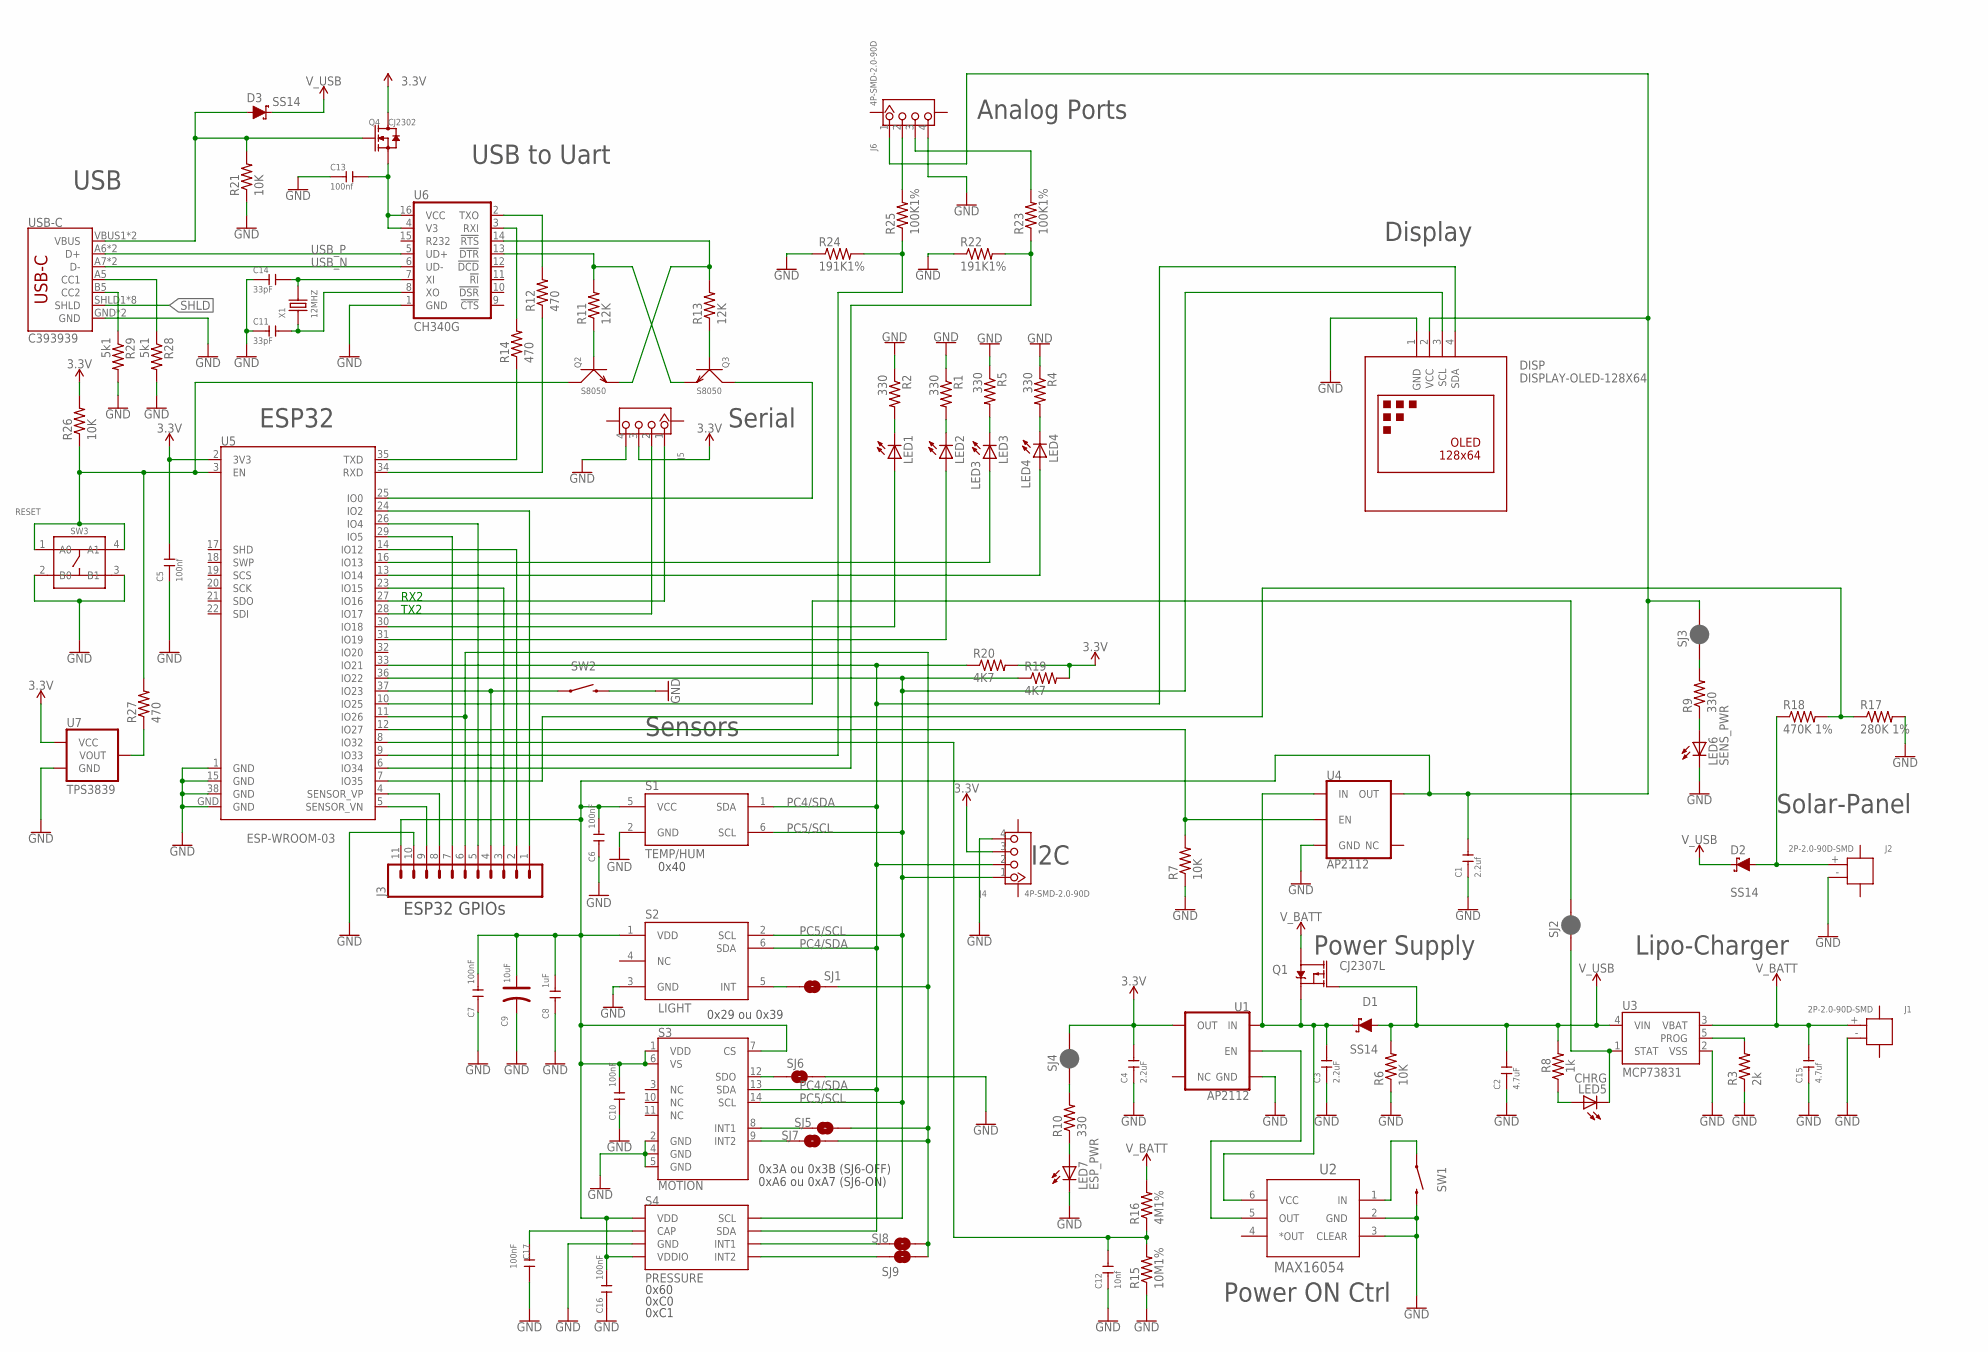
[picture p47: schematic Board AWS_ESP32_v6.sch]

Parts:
C1: 2.2uf; C0603
C2: 4.7uF; C0603
C3, C4: 2.2uF; C0603
C5, C13: 100nf; C0603
C6, C7, C10, C16, C17: 100nF; C0603
C8: 1uF; C0805
C9: 10uF; AVX-A
C11, C14: 33pF; C0603
C12: 10nf; C0603
C15: 4.7uf; C0603
D1, D2, D3: SS14; SMA-DIODE
DISP: DISPLAY-OLED-128X64; DISPLAY-OLED-128X64-I2C
J1, J2: 2P-2.0-90D-SMD; HW2-SMD-2.0-90D
J3: CONN_11; 1X11
J4, J5, J6: 4P-SMD-2.0-90D; HW4-SMD-2.0-90D
LED1: LED1; LED-0603
LED2: LED2; LED-0603
LED3: LED3; LED-0603
LED4: LED4; LED-0603
LED5: CHRG; LED-0603
LED6: SENS_PWR; LED-0603
LED7: ESP_PWR; LED-0603
Q1: CJ2307L; SOT23-3
Q2, Q3: S8050; SOT-23
Q4: CJ2302; SOT-23
R1, R2, R4, R5, R9, R10: 330; 0805
R3: 2k; 0805
R6, R7, R21, R26: 10K; 0805
R8: 1k; 0805
R11, R13: 12K; 0805
R12, R14, R27: 470; 0805
R15: 10M1%; 0805
R16: 4M1%; 0805
R17: 280K 1%; 0805
R18: 470K 1%; 0805
R19, R20: 4K7; 0805
R22, R24: 191K1%; 0805
R23, R25: 100K1%; 0805
R28, R29: 5k1; 0805
S1: TEMP/HUM; WSON6
S2: LIGHT; FN-6
S3: MOTION; LGA-14
S4: PRESSURE; LGA8
SJ1: IRQ_LIGHT; SJ_2S-NO
SJ2, SJ3, SJ4: JUMPER-SMT_2_NC_PASTE_SILK; SMT-JUMPER_2_NC_PASTE_SILK
SJ5, SJ7, SJ8: INT1; SJ_2S-NO
SJ6: ADXL_ADDRESS; SJ_2S-NO
SJ9: INT2; SJ_2S-NO
SW1, SW2: MOMENTARY-SWITCH-SPST-SMD-6.0X3.5MM; TACTILE_SWITCH_SMD_6.0X3.5MM
SW3: RESET; SW4-SMD-6.0X6.0X5.0MM
U1, U4: AP2112; SOT23-5
U2: MAX16054; SOT23-6
U3: MCP73831; SOT23-5
U5: ESP-WROOM-03
U6: CH340G; SO016
U7: TPS3839; SOT23-3
USB-C: C393939; SPARKFUN-CONNECTORS_USB-C-16P
X1: 12MHZ; X2-SMD-5.0X3.2X1.3MM

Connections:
3.3V: C4.2, C5.2, J4.3, J5.3, Q4.3 (D), R19.2, R20.2, R26.2, SJ4.2, U1.5 (OUT), U5.2 (3V3), U7.3 (VCC)
BEE_RESET: Q2.3 (C), R26.1, R27.2, SW3.1 (A0), SW3.4 (A1), U5.3 (EN)
GND: C1.1, C2.1, C3.1, C4.1, C5.1, C6.1, C7.1, C8.2, C9.-, C10.1, C11.1, C12.1, C13.1, C14.1, C15.1, C16.1, C17.2, DISP.1 (GND), J1.- (2), J2.- (2), J3.10, J4.4, J5.4, J6.4, LED6.C, LED7.C, R1.1, R2.1, R3.1, R4.1, R5.1, R6.1, R7.1, R15.1, R17.2, R21.1, R22.1, R24.1, R28.2, R29.2, S1.2 (GND), S2.3 (GND), S3.2 (GND), S3.4 (GND), S3.5 (GND), S4.3 (GND), SJ6.2, SW1.2, SW2.2, SW3.2 (B0), SW3.3 (B1), U1.2 (GND), U2.2 (GND), U2.3 (CLEAR), U3.2 (VSS), U4.2 (GND), U5.1 (GND), U5.15 (GND), U5.38 (GND), U5.GND, U6.1 (GND), U7.1 (GND), USB-C.GND, USB-C.GND2 (GND)
unnamed: C1.2, C6.2, C7.2, C8.1, C9.+, C10.2, C16.2, DISP.2 (VCC), J3.11, J6.1, S1.5 (VCC), S2.1 (VDD), S3.1 (VDD), S3.6 (VS), S3.7 (CS), S4.1 (VDD), S4.4 (VDDIO), SJ3.2, U4.5 (OUT)
unnamed: LED3.A, U5.16 (IO13)
unnamed: D2.A, J2.+ (1), R18.1
unnamed: R27.1, U7.2 (VOUT)
unnamed: LED1.A, U5.30 (IO18)
unnamed: J3.5, U5.26 (IO4)
unnamed: C17.1, S4.2 (CAP)
unnamed: S3.8 (INT1), SJ5.1
unnamed: S3.9 (INT2), SJ7.1
unnamed: C13.2, Q4.2 (S), U6.4 (V3), U6.16 (VCC)
unnamed: LED2.A, U5.31 (IO19)
unnamed: C12.2, R15.2, R16.1, U5.8 (IO32)
unnamed: J3.4, SW2.1, U5.37 (IO23)
unnamed: SW1.1, U2.1 (IN)
unnamed: C14.2, U6.7 (XI), X1.2
unnamed: J5.1, U5.27 (IO16)
unnamed: J5.2, U5.28 (IO17)
unnamed: U1.3 (EN), U2.5 (OUT)
unnamed: Q2.1 (B), R11.1
unnamed: C11.2, U6.8 (XO), X1.1
unnamed: S3.12 (SDO), SJ6.1
unnamed: R3.2, U3.5 (PROG)
unnamed: D3.A, Q4.1 (G), R21.2, USB-C.VBUS1 (VBUS), USB-C.VBUS2 (VBUS)
unnamed: R29.1, USB-C.B5 (CC2)
unnamed: S4.6 (INT1), SJ8.1
unnamed: S4.5 (INT2), SJ9.1
unnamed: S2.5 (INT), SJ1.1
unnamed: R12.1, U5.34 (RXD)
unnamed: R14.1, U5.35 (TXD)
unnamed: Q3.1 (B), R13.1
unnamed: R28.1, USB-C.A5 (CC1)
unnamed: LED1.C, R2.2
unnamed: LED2.C, R1.2
unnamed: Q2.2 (E), R13.2, U6.14 (!RTS)
unnamed: LED4.C, R4.2
unnamed: LED3.C, R5.2
unnamed: Q3.3 (C), U5.25 (IO0)
unnamed: Q3.2 (E), R11.2, U6.13 (!DTR)
unnamed: R24.2, R25.1, U5.9 (IO33)
unnamed: R22.2, R23.1, U5.6 (IO34)
unnamed: J6.2, R25.2
unnamed: J6.3, R23.2
unnamed: R17.1, R18.2, U5.7 (IO35)
unnamed: R14.2, U6.3 (RXI)
unnamed: R12.2, U6.2 (TXO)
unnamed: SJ2.2, U5.10 (IO25)
unnamed: J3.7, U5.29 (IO5)
unnamed: LED5.A, R8.1
unnamed: C3.2, D1.C, Q1.2 (S), U1.1 (IN), U2.6 (VCC), U4.1 (IN)
unnamed: LED7.A, R10.1
unnamed: R10.2, SJ4.1
unnamed: LED5.C, SJ2.1, U3.1 (STAT)
unnamed: LED4.A, U5.13 (IO14)
unnamed: LED6.A, R9.1
unnamed: R7.2, U4.3 (EN), U5.12 (IO27)
unnamed: R9.2, SJ3.1
unnamed: J3.9, U5.5 (SENSOR_VN)
unnamed: J3.8, U5.4 (SENSOR_VP)
unnamed: J3.3, U5.23 (IO15)
unnamed: J3.2, U5.14 (IO12)
unnamed: J3.1, U5.24 (IO2)
PC4/SDA: DISP.4 (SDA), J4.2, R20.1, S1.1 (SDA), S2.6 (SDA), S3.13 (SDA), S4.7 (SDA), U5.33 (IO21)
PC5/SCL: DISP.3 (SCL), J4.1, R19.1, S1.6 (SCL), S2.2 (SCL), S3.14 (SCL), S4.8 (SCL), U5.36 (IO22)
PD3/IRQ: J3.6, SJ1.2, SJ5.2, SJ7.2, SJ8.2, SJ9.2, U5.11 (IO26)
SHLD: USB-C.SHLD1 (SHLD), USB-C.SHLD2 (SHLD), USB-C.SHLD3 (SHLD), USB-C.SHLD4 (SHLD), USB-C.SHLD5 (SHLD), USB-C.SHLD6 (SHLD), USB-C.SHLD7 (SHLD), USB-C.SHLD8 (SHLD)
USB_N: U6.6 (UD-), USB-C.A7 (D-), USB-C.B7 (D-)
USB_P: U6.5 (UD+), USB-C.A6 (D+), USB-C.B6 (D+)
V_BATT: C15.2, J1.+ (1), Q1.3 (D), R16.2, U3.3 (VBAT)
V_USB: C2.2, D1.A, D2.C, D3.C, Q1.1 (G), R6.2, R8.2, U3.4 (VIN)

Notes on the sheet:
USB
I2C
Sensors
0x60
0xC1
0xC0
0x29 ou 0x39
0x40
Serial
ESP32
Power Supply
USB to Uart
Analog Ports
Lipo-Charger
ESP32 GPIOs
RX2
TX2
Solar-Panel
Display
0x3A ou 0x3B (SJ6-OFF)
0xA6 ou 0xA7 (SJ6-ON)
Power ON Ctrl

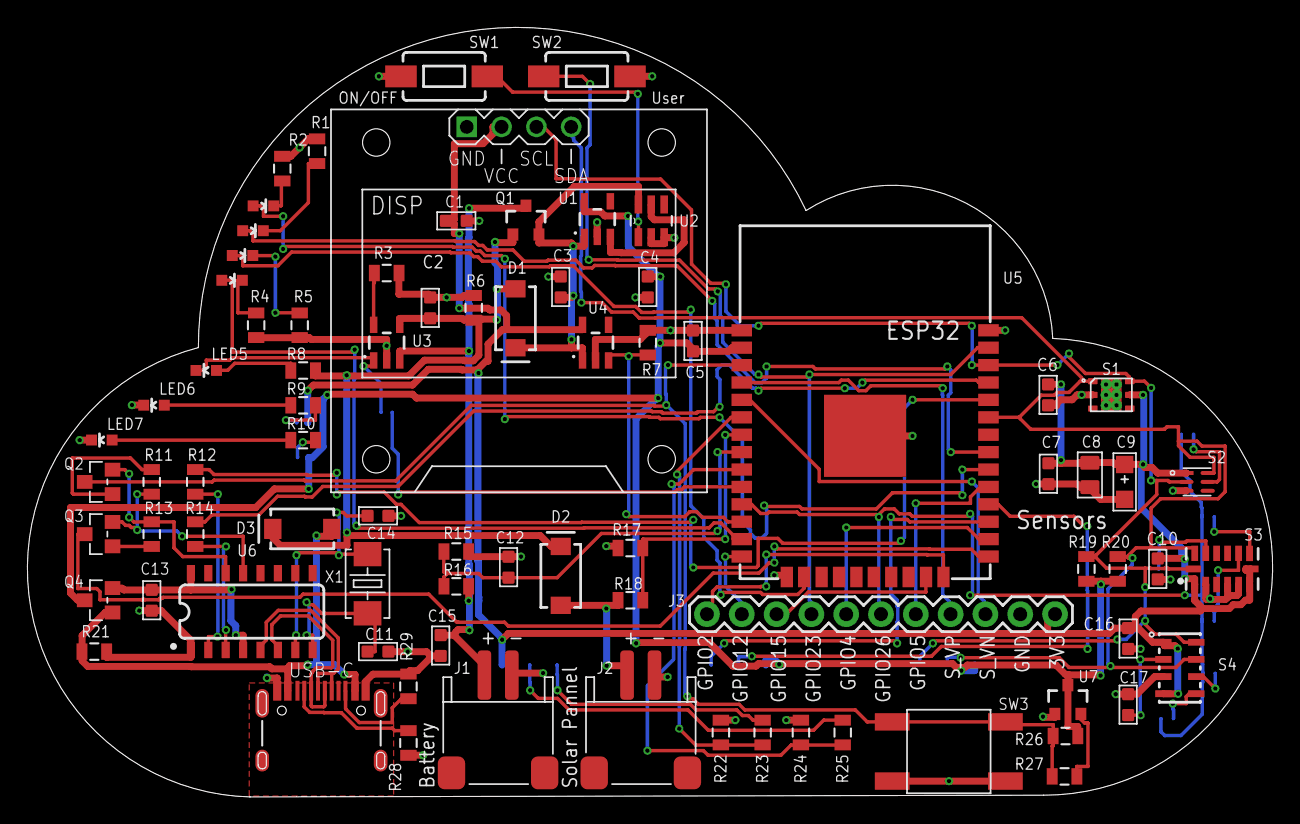
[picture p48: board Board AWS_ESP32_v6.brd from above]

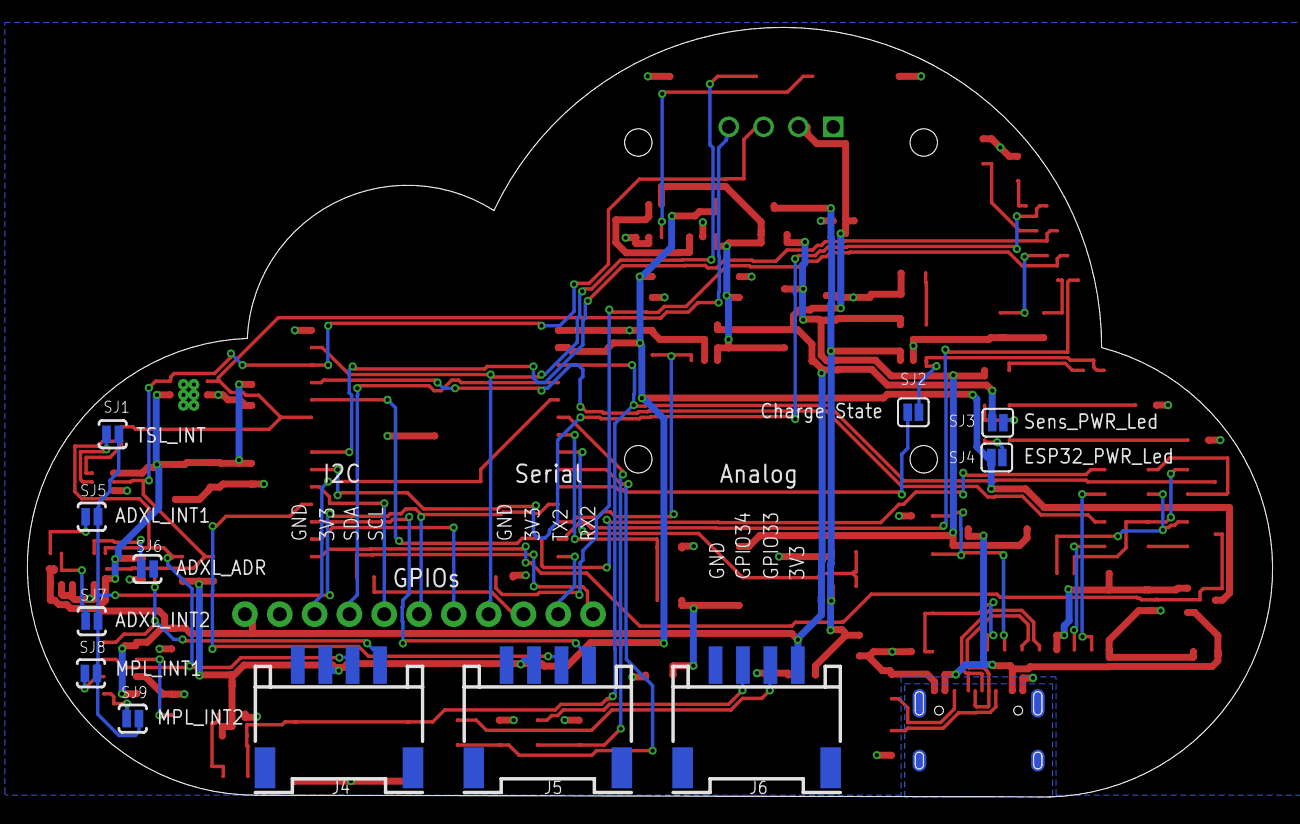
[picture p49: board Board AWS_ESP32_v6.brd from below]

Board: 2 copper layers, 90.8 x 56.1 mm, 92 parts (12 on the bottom side), 72 nets.

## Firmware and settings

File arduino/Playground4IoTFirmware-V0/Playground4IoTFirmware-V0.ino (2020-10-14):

/****** ESP32 GPIO MAP ******

  GPIO0 -> Firmware Upload Mode
  GPIO1 -> TXD
  GPIO3 -> RXD

  GPIO13 -> Led 3
  GPIO14 -> Led 4
  GPIO18 -> Led 1
  GPIO19 -> Led 2

  GPIO16 -> Serial 2 (RX)
  GPIO17 -> Serial 2 (TX)

  GPIO21 -> I2C (SDA)
  GPIO22 -> I2C (SCL)

  GPIO23 -> User Button (0=pressed / 1=not pressed)

  GPIO25 -> Battery State (0=Charging / 1=charged or not charging)
  GPIO26 -> I2C sensors Interrupt Input (optional- must be configured conecting SJ1 or SJ5 or SJ7 or SJ8 or SJ9)

  GPIO27 -> Sensors and Display Power control (0=Power OFF / 1=Power ON)

  GPIO32 -> Battery voltage (Analog INPUT)
  GPIO33 -> (External Analog INPUT)
  GPIO34 -> (External Analog INPUT)
  GPIO35 -> Solar Panel voltage (Analog INPUT)

  GPIO6 a GPIO11 -> Do not Use (Flash Memory)

  GPIO2 -> External GPIO
  GPIO4 -> External GPIO
  GPIO5 ->  External GPIO
  GPI12 ->  External GPIO
  GPI15 ->  External GPIO
  GPI12 ->  External GPIO
  SensorVP - >  External GPIO
  SensorVN - >  External GPIO

*/
#include "secrets.h"
#include <WiFiClientSecure.h>
#include <MQTTClient.h>
#include <ArduinoJson.h>


#include <WiFi.h>
#include <ESPmDNS.h>
#include <WiFiUdp.h>
#include <ArduinoOTA.h>
#include <Wire.h>
#include "ssd1306.h"
#include <Adafruit_Sensor.h>
#include <Adafruit_ADXL345_U.h>
#include "ClosedCube_HDC1080.h"
ClosedCube_HDC1080 hdc1080;

// Include logo images
#include "Logo_AWS.h"


#define hostName "MyPlayground-NAMEHERE"

const char* ssid = "surfing-iot";
const char* password = "iotiotiot";

// The MQTT topics that this device should publish/subscribe
#define AWS_IOT_PUBLISH_TOPIC   "playground/sensors"
#define AWS_IOT_SUBSCRIBE_TOPIC "playground/command"

/* Assign a unique ID to this sensor at the same time */
Adafruit_ADXL345_Unified accel = Adafruit_ADXL345_Unified(12345);

// I2C address of the TSL2571 0x39(57)
#define Addr 0x39
byte data[4];
double luminosidade ;

#define SSD1306_128_64


// MPL3115A2
#define STATUS     0x00
#define OUT_P_MSB  0x01
#define OUT_P_CSB  0x02
#define OUT_P_LSB  0x03
#define OUT_T_MSB  0x04
#define OUT_T_LSB  0x05
#define DR_STATUS  0x06
#define OUT_P_DELTA_MSB  0x07
#define OUT_P_DELTA_CSB  0x08
#define OUT_P_DELTA_LSB  0x09
#define OUT_T_DELTA_MSB  0x0A
#define OUT_T_DELTA_LSB  0x0B
#define WHO_AM_I   0x0C
#define F_STATUS   0x0D
#define F_DATA     0x0E
#define F_SETUP    0x0F
#define TIME_DLY   0x10
#define SYSMOD     0x11
#define INT_SOURCE 0x12
#define PT_DATA_CFG 0x13
#define BAR_IN_MSB 0x14
#define BAR_IN_LSB 0x15
#define P_TGT_MSB  0x16
#define P_TGT_LSB  0x17
#define T_TGT      0x18
#define P_WND_MSB  0x19
#define P_WND_LSB  0x1A
#define T_WND      0x1B
#define P_MIN_MSB  0x1C
#define P_MIN_CSB  0x1D
#define P_MIN_LSB  0x1E
#define T_MIN_MSB  0x1F
#define T_MIN_LSB  0x20
#define P_MAX_MSB  0x21
#define P_MAX_CSB  0x22
#define P_MAX_LSB  0x23
#define T_MAX_MSB  0x24
#define T_MAX_LSB  0x25
#define CTRL_REG1  0x26
#define CTRL_REG2  0x27
#define CTRL_REG3  0x28
#define CTRL_REG4  0x29
#define CTRL_REG5  0x2A
#define OFF_P      0x2B
#define OFF_T      0x2C
#define OFF_H      0x2D

#define MPL3115A2_ADDRESS 0x60 // 7-bit I2C address

long startTime;


#define led1 18
#define led2 19
#define led3 13
#define led4 14
#define delayLeds 50
bool direcao = false;
int userButtonState = 1;

float Temperatura;
float Umidade;
float Luminosidade;

float Altitude;
float Pressao;

double solarPanelVoltage;
double batteryVoltage;
bool batteryChargeStatus ;  //(1-CHARGED)
int batteryStatusPerCent;

#define batteryStatusPin 25

float Xacc;
float Yacc;
float Zacc;


#define SSD1306_128_32


WiFiClientSecure net = WiFiClientSecure();
MQTTClient client = MQTTClient(512);

#define SECRET
#define THINGNAME "play1"


void setup() {
  pinMode(27, OUTPUT);      //power ON sensors and OLED display
  digitalWrite(27, HIGH);
  pinMode(25, INPUT);
  pinMode(23, INPUT_PULLUP);   //enable user button pull-up
  delay(2000);

  Wire.begin();
  ssd1306_128x64_i2c_init();                     // Initialze SSD1306 OLED display
  ssd1306_clearScreen( );
  ssd1306_drawBitmap(0, 0, 128, 64, Logo_AWS);
  delay(3000);

  ssd1306_clearScreen( );
  ssd1306_setFixedFont(ssd1306xled_font5x7);            // Set font type (default 6x8)
  //oled.setTextXY(0,0);              // Set cursor position, start of line 0

  Serial.begin(115200);
  pinMode(led1, OUTPUT);
  pinMode(led2, OUTPUT);
  pinMode(led3, OUTPUT);
  pinMode(led4, OUTPUT);

  inicializaAcelerometro();
  inicializaHDC1080();
  init_TSL2571();
  inicializa_MPL3115A2();

  Serial.println("Booting");
  WiFi.mode(WIFI_STA);
  WiFi.begin(ssid, password);
  while (WiFi.waitForConnectResult() != WL_CONNECTED) {
    Serial.println("Connection Failed! Rebooting...");
    delay(5000);
    ESP.restart();
  }

  inicializa_OTA();

  Serial.println("Ready");
  Serial.print("IP address: ");
  Serial.println(WiFi.localIP());
  IPoled();
  connectAWS();
}

void loop() {
  ArduinoOTA.handle();
  testeLeds();
  leAcelerometro();
  le_HDC1080();
  le_MPL3115A2();
  le_voltagem_painelSolar();
  le_TSL2571();
  le_Altitude();
  le_voltagem_bateria();
  le_battery_status();
  userButtonState = digitalRead(23);
  buttonOled();
  publishSensors();
  client.loop();
}








void connectAWS()
{
  /*  WiFi.mode(WIFI_STA);
    WiFi.begin(WIFI_SSID, WIFI_PASSWORD);

    Serial.println("Connecting to Wi-Fi");

    while (WiFi.status() != WL_CONNECTED){
      delay(500);
      Serial.print(".");
    }*/

  // Configure WiFiClientSecure to use the AWS IoT device credentials
  net.setCACert(AWS_CERT_CA);
  net.setCertificate(AWS_CERT_CRT);
  net.setPrivateKey(AWS_CERT_PRIVATE);

  // Connect to the MQTT broker on the AWS endpoint we defined earlier
  client.begin(AWS_IOT_ENDPOINT, 8883, net);

  // Create a message handler
  client.onMessage(messageHandler);

  Serial.print("Connecting to AWS IOT");

  while (!client.connect(THINGNAME)) {
    Serial.print(".");
    delay(100);
  }

  if (!client.connected()) {
    Serial.println("AWS IoT Timeout!");
    return;
  }

  // Subscribe to a topic
  client.subscribe(AWS_IOT_SUBSCRIBE_TOPIC);

  Serial.println("AWS IoT Connected!");
}




void publishSensors()
{
  Serial.println("publishing sensors to MQTT");
  StaticJsonDocument<200> doc;
  doc["time"] = millis();
  doc["humidity"] = Umidade;
  doc["temperature"] = Temperatura;
  doc["light"] = Luminosidade;
  doc["altitude"] = Altitude;
  doc["pressure"] = Pressao;
  doc["solarPanelVoltage"] = solarPanelVoltage;
  doc["batteryVoltage"] = batteryVoltage;
  doc["batteryChargeStatus"] = batteryChargeStatus;
  doc["batteryStatusPerCent"] = batteryStatusPerCent;
  doc["X"] = Xacc;
  doc["Y"] = Yacc;
  doc["Z"] = Zacc;

  char jsonBuffer[512];
  serializeJson(doc, jsonBuffer); // print to client

  client.publish(AWS_IOT_PUBLISH_TOPIC, jsonBuffer);
}

void messageHandler(String &topic, String &payload) {
  Serial.println("receiving MQTT message");
  Serial.println("incoming: " + topic + " - " + payload);

  //  StaticJsonDocument<200> doc;
  //  deserializeJson(doc, payload);
  //  const char* message = doc["message"];
}

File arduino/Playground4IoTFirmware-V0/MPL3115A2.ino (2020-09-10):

void le_MPL3115A2(){
  Pressao = readPressure();
  oledPressao();
  setModeAltimeter(); // Measure altitude above sea level in meters
  delay(300);
}

void le_Altitude(){
  delay(300);
  Altitude = readAltitude();
  oledAltitude();
  setModeBarometer(); // Measure pressure in Pascals from 20 to 110 kPa
  delay(300);
}



void inicializa_MPL3115A2(){
   if(IIC_Read(WHO_AM_I) == 196) 
    Serial.println("MPL3115A2 online!");
  else
    Serial.println("No response from MPL3115A2 - check connections");

  // Configure the sensor
  setModeAltimeter(); // Measure altitude above sea level in meters
  //setModeBarometer(); // Measure pressure in Pascals from 20 to 110 kPa

  setOversampleRate(7); // Set Oversample to the recommended 128
  enableEventFlags(); // Enable all three pressure and temp event flags
}


//Returns the number of meters above sea level
float readAltitude(){
  toggleOneShot(); //Toggle the OST bit causing the sensor to immediately take another reading

  //Wait for PDR bit, indicates we have new pressure data
  int counter = 0;
  while( (IIC_Read(STATUS) & (1<<1)) == 0){
      if(++counter > 100) return(-999); //Error out
      delay(1);
  }
  
  // Read pressure registers
  Wire.beginTransmission(MPL3115A2_ADDRESS);
  Wire.write(OUT_P_MSB);  // Address of data to get
  Wire.endTransmission(false); // Send data to I2C dev with option for a repeated start. THIS IS NECESSARY and not supported before Arduino V1.0.1!
  Wire.requestFrom(MPL3115A2_ADDRESS, 3); // Request three bytes

  //Wait for data to become available
  counter = 0;
  while(Wire.available() < 3){
    if(counter++ > 100) return(-999); //Error out
    delay(1);
  }

  byte msb, csb, lsb;
  msb = Wire.read();
  csb = Wire.read();
  lsb = Wire.read();

  toggleOneShot(); //Toggle the OST bit causing the sensor to immediately take another reading

  // The least significant bytes l_altitude and l_temp are 4-bit,
  // fractional values, so you must cast the calulation in (float),
  // shift the value over 4 spots to the right and divide by 16 (since 
  // there are 16 values in 4-bits). 
  float tempcsb = (lsb>>4)/16.0;

  float altitude = (float)( (msb << 8) | csb) + tempcsb;

  Serial.print("altitude:");
  Serial.println(altitude);
  

  return(altitude);
}

//Returns the number of feet above sea level
float readAltitudeFt(){
  return(readAltitude() * 3.28084);
}

//Reads the current pressure in Pa
//Unit must be set in barometric pressure mode
float readPressure(){
  toggleOneShot(); //Toggle the OST bit causing the sensor to immediately take another reading

  //Wait for PDR bit, indicates we have new pressure data
  int counter = 0;
  while( (IIC_Read(STATUS) & (1<<2)) == 0){
      if(++counter > 100) return(-999); //Error out
      delay(1);
  }

  // Read pressure registers
  Wire.beginTransmission(MPL3115A2_ADDRESS);
  Wire.write(OUT_P_MSB);  // Address of data to get
  Wire.endTransmission(false); // Send data to I2C dev with option for a repeated start. THIS IS NECESSARY and not supported before Arduino V1.0.1!
  Wire.requestFrom(MPL3115A2_ADDRESS, 3); // Request three bytes

  //Wait for data to become available
  counter = 0;
  while(Wire.available() < 3){
    if(counter++ > 100) return(-999); //Error out
    delay(1);
  }

  byte msb, csb, lsb;
  msb = Wire.read();
  csb = Wire.read();
  lsb = Wire.read();

  toggleOneShot(); //Toggle the OST bit causing the sensor to immediately take another reading

  // Pressure comes back as a left shifted 20 bit number
  long pressure_whole = (long)msb<<16 | (long)csb<<8 | (long)lsb;
  pressure_whole >>= 6; //Pressure is an 18 bit number with 2 bits of decimal. Get rid of decimal portion.

  lsb &= 0b00110000; //Bits 5/4 represent the fractional component
  lsb >>= 4; //Get it right aligned
  float pressure_decimal = (float)lsb/4.0; //Turn it into fraction

  float pressure = (float)pressure_whole + pressure_decimal;

  Serial.print("Pressão:");
  Serial.println(pressure);


  return(pressure);
}

float readTemp(){
  toggleOneShot(); //Toggle the OST bit causing the sensor to immediately take another reading

  //Wait for TDR bit, indicates we have new temp data
  int counter = 0;
  while( (IIC_Read(STATUS) & (1<<1)) == 0){
      if(++counter > 100) return(-999); //Error out
      delay(1);
  }
  
  // Read temperature registers
  Wire.beginTransmission(MPL3115A2_ADDRESS);
  Wire.write(OUT_T_MSB);  // Address of data to get
  Wire.endTransmission(false); // Send data to I2C dev with option for a repeated start. THIS IS NECESSARY and not supported before Arduino V1.0.1!
  Wire.requestFrom(MPL3115A2_ADDRESS, 2); // Request two bytes

  //Wait for data to become available
  counter = 0;
  while(Wire.available() < 2){
    if(++counter > 100) return(-999); //Error out
    delay(1);
  }

  byte msb, lsb;
  msb = Wire.read();
  lsb = Wire.read();
  
  // The least significant bytes l_altitude and l_temp are 4-bit,
  // fractional values, so you must cast the calulation in (float),
  // shift the value over 4 spots to the right and divide by 16 (since 
  // there are 16 values in 4-bits). 
  float templsb = (lsb>>4)/16.0; //temp, fraction of a degree

  float temperature = (float)(msb + templsb);

  return(temperature);
}

//Give me temperature in fahrenheit!
float readTempF(){
  return((readTemp() * 9.0)/ 5.0 + 32.0); // Convert celsius to fahrenheit
}

//Sets the mode to Barometer
//CTRL_REG1, ALT bit
void setModeBarometer(){
  byte tempSetting = IIC_Read(CTRL_REG1); //Read current settings
  tempSetting &= ~(1<<7); //Clear ALT bit
  IIC_Write(CTRL_REG1, tempSetting);
}

//Sets the mode to Altimeter
//CTRL_REG1, ALT bit
void setModeAltimeter(){
  byte tempSetting = IIC_Read(CTRL_REG1); //Read current settings
  tempSetting |= (1<<7); //Set ALT bit
  IIC_Write(CTRL_REG1, tempSetting);
}

//Puts the sensor in standby mode
//This is needed so that we can modify the major control registers
void setModeStandby(){
  byte tempSetting = IIC_Read(CTRL_REG1); //Read current settings
  tempSetting &= ~(1<<0); //Clear SBYB bit for Standby mode
  IIC_Write(CTRL_REG1, tempSetting);
}

//Puts the sensor in active mode
//This is needed so that we can modify the major control registers
void setModeActive(){
  byte tempSetting = IIC_Read(CTRL_REG1); //Read current settings
  tempSetting |= (1<<0); //Set SBYB bit for Active mode
  IIC_Write(CTRL_REG1, tempSetting);
}

//Setup FIFO mode to one of three modes. See page 26, table 31
//From user jr4284
void setFIFOMode(byte f_Mode){
  if (f_Mode > 3) f_Mode = 3; // FIFO value cannot exceed 3.
  f_Mode <<= 6; // Shift FIFO byte left 6 to put it in bits 6, 7.

  byte tempSetting = IIC_Read(F_SETUP); //Read current settings
  tempSetting &= ~(3<<6); // clear bits 6, 7
  tempSetting |= f_Mode; //Mask in new FIFO bits
  IIC_Write(F_SETUP, tempSetting);
}
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

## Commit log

2020-10-13 adds missing libraries ArduinoJson and arduino-mqtt
2020-10-19 case 3d

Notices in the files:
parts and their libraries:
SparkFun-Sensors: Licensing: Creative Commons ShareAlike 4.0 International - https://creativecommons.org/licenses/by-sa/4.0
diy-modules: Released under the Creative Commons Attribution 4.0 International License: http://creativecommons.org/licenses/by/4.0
